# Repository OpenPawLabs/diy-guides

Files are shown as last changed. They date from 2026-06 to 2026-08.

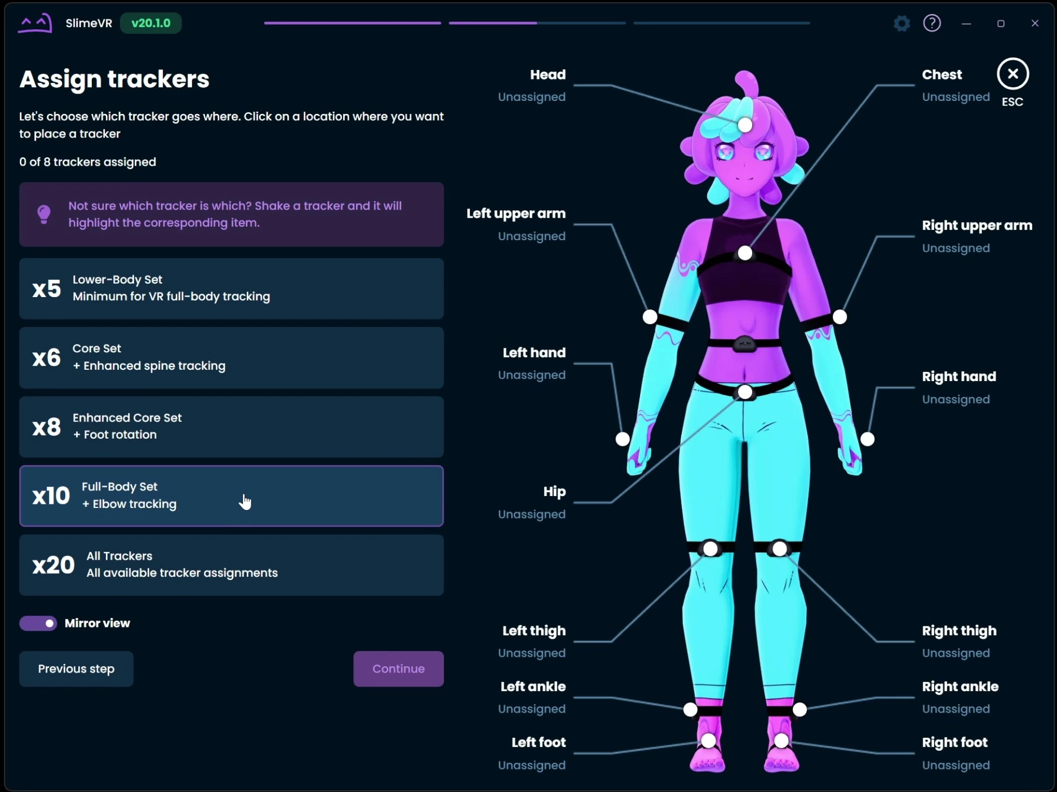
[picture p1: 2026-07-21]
common/0-onetime-tracker-setup/images/slimevr-assign-trackers.webp

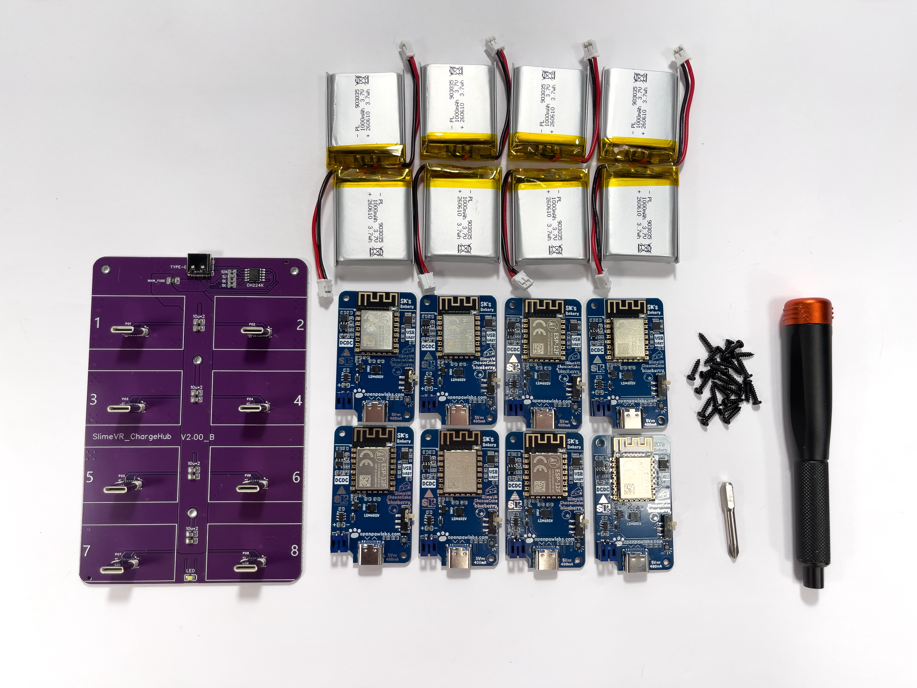
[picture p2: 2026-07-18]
bb-lsm6dsv/0-overview/images/img-4715.webp

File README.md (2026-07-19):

# diy-guides

Contains all of our DIY guides written for OpenPawLabs! Help fix/contribute today!

## Project manifests

Each project folder (for example `bb-lsm6dsv/`) includes a `project.json` that is the source of truth for:

- Project title and description
- **Ordered** list of guides shown on the docs site (cards, prev/next, progress)
- Per-guide card descriptions, plus `optional` / `shared` flags
- Optional route `slug` overrides (used for shared `common/` guides)

Guide display fields (`title`, `difficulty`, `timeEstimate`, `heroImage`, steps) still come from each guide’s `guide.mdx` header — do not duplicate titles in the manifest.

### Conventions

| Field | Meaning |
|---|---|
| `overview` | Project-relative path of the guide whose hero backs the project card |
| `guides[].path` | Project-relative for local guides (`0-overview`), or repo-root-relative for shared guides (`common/…`) |
| `guides[].slug` | Defaults to the final path segment; set only when the URL should differ |
| Array order | Site order |

When you add, remove, or reorder guides, edit `project.json` in the same change. Folders not listed in the manifest stay invisible on the site (useful for WIP drafts). The docs site validates that every listed path has a `guide.mdx`.

## Image scripts

Guides reference local rasters under each guide’s `images/` folder. Two scripts help keep those assets small and tidy.

### Setup

```bash
pip install -r scripts/requirements.txt
```

### Convert referenced images to WebP

Converts every PNG/JPG referenced by a `guide.mdx` to WebP (default quality `92`, full resolution, alpha preserved), rewrites the MDX paths, and deletes the converted originals.

```bash
# Preview without writing
python scripts/convert-images-to-webp.py --dry-run

# Convert (lossy WebP, quality 92)
python scripts/convert-images-to-webp.py

# Optional: custom quality or lossless encode
python scripts/convert-images-to-webp.py --quality 95
python scripts/convert-images-to-webp.py --lossless
```

### Clean up unused images

Reports files under any `images/` directory that no `guide.mdx` references. Deletion is opt-in.

```bash
# List unused files and reclaimable size
python scripts/cleanup-unused-images.py

# Only consider raster images in the report
python scripts/cleanup-unused-images.py --rasters-only

# Delete unused rasters (non-rasters need an extra flag)
python scripts/cleanup-unused-images.py --delete
python scripts/cleanup-unused-images.py --delete --include-non-rasters

# --delete aborts if nothing looks referenced, or if ≥50% of images
# look unused (pass --force only after reviewing that report)
python scripts/cleanup-unused-images.py --delete --force
```

Suggested workflow: convert referenced images, review the cleanup report, then delete unused files.

### Responsive size variants (build hosts, not this repo)

Do **not** commit thumbnail derivatives here. The docs site (and other publishers) run
[`diy-guide-images`](https://github.com/OpenPawLabs/diy-guides-ui-react) from
`@openpawlabs/diy-guides-ui` after syncing this tree, writing AVIF width variants
under `images/thumbnails/` (plus `variants.json`). Authors only commit canonical
sources under each guide’s `images/` folder. Delete `images/thumbnails/` locally
to force a regenerate.

To preview locally:

```bash
pnpm --dir ../diy-guides-ui-react exec diy-guide-images ./bb-lsm6dsv/0-overview
```

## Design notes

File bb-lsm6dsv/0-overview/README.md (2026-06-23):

Contains the guide that references what materials/tools the user needs to acquire to complete the guide. Gives a general overview of the project and acts as the starting point for users.

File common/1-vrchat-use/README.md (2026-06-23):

Walks the user through the steps required in VRChat every time they use their trackers. Quick calibrate in SlimeVR, and click Calibrate in VRChat!

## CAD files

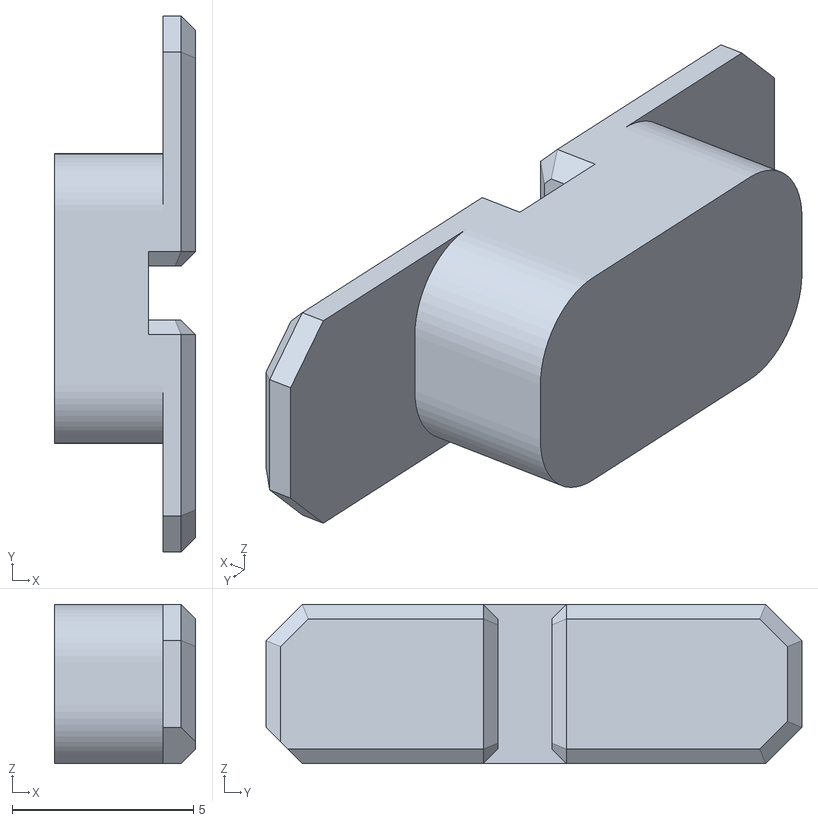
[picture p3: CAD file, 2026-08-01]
bb-lsm6dsv/1-3d-prints/files/003-SW.stl
3.90 x 14.8 x 4.40

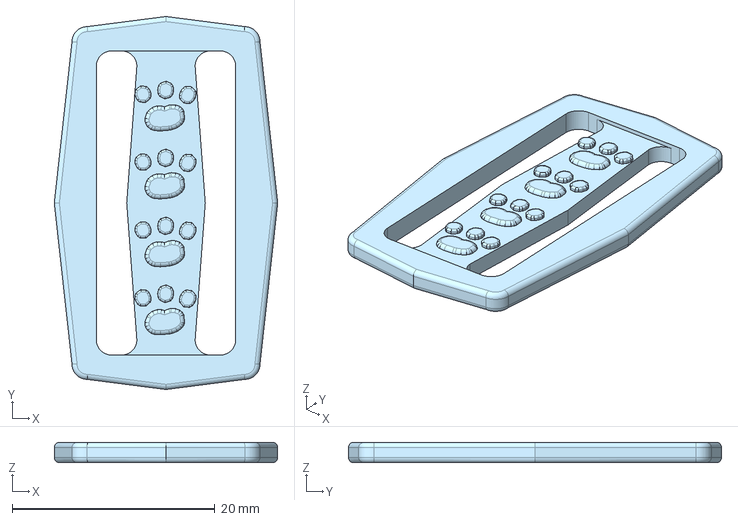
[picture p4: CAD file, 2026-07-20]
bb-lsm6dsv/1-3d-prints/images/glide-slide-v1.step
22.1 x 36.8 x 2.00 mm

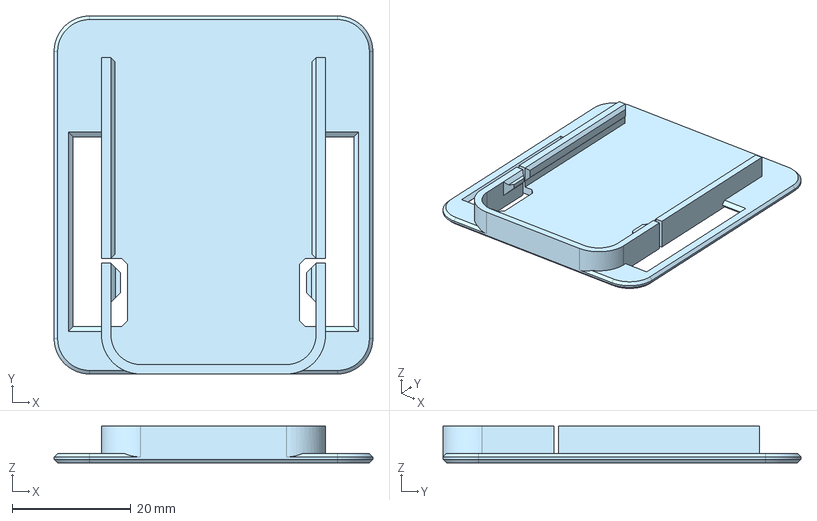
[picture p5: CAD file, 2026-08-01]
bb-lsm6dsv/1-3d-prints/files/openpaw-slide-mount-v5.step
53.8 x 60.4 x 6.20 mm

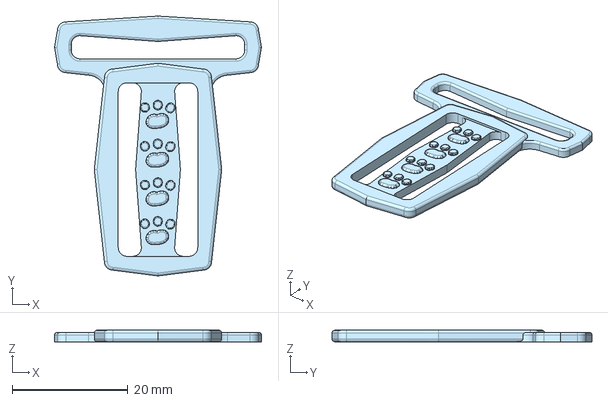
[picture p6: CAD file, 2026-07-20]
bb-lsm6dsv/1-3d-prints/images/3-way-glide-slide-v1.step
35.8 x 45.0 x 2.00 mm

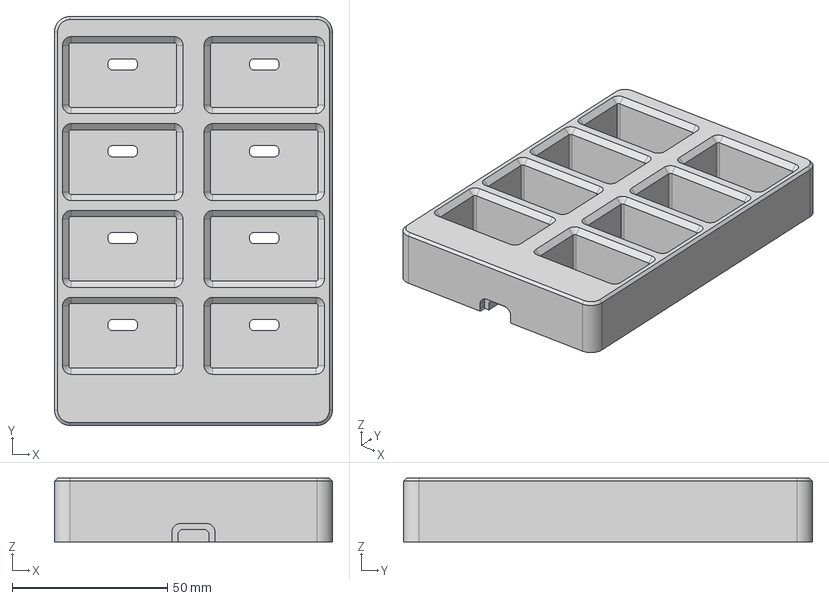
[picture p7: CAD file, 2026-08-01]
bb-lsm6dsv/1-3d-prints/files/charger-dock-dock-top-v3.step
89.6 x 131.8 x 20.6 mm

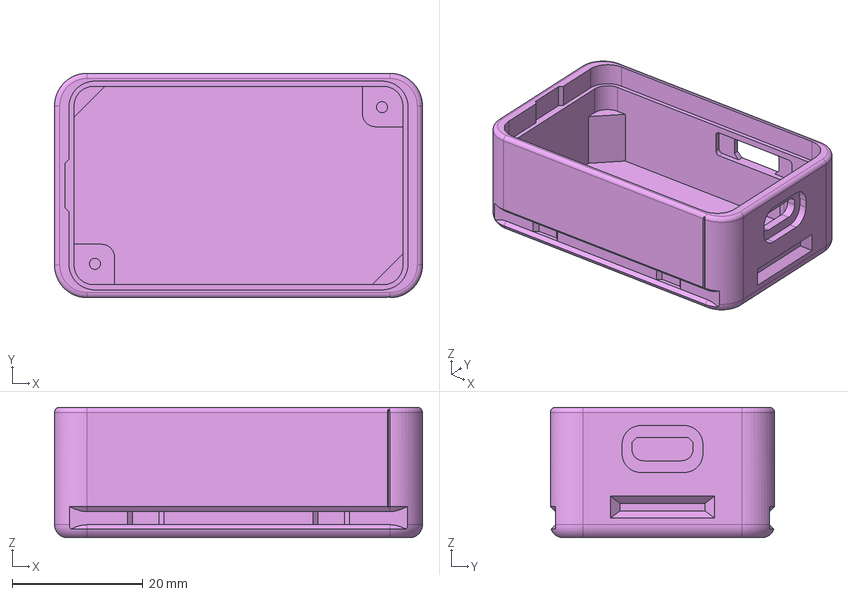
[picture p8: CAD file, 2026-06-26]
bb-lsm6dsv/1-3d-prints/images/openpaw-tracker-case-v7.step
56.4 x 34.4 x 20.0 mm

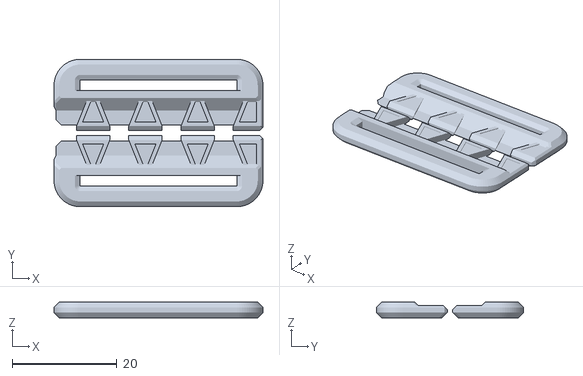
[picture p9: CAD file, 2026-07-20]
bb-lsm6dsv/1-3d-prints/files/latch-30mm-a-moderahn.stl
40.0 x 28.2 x 3.00

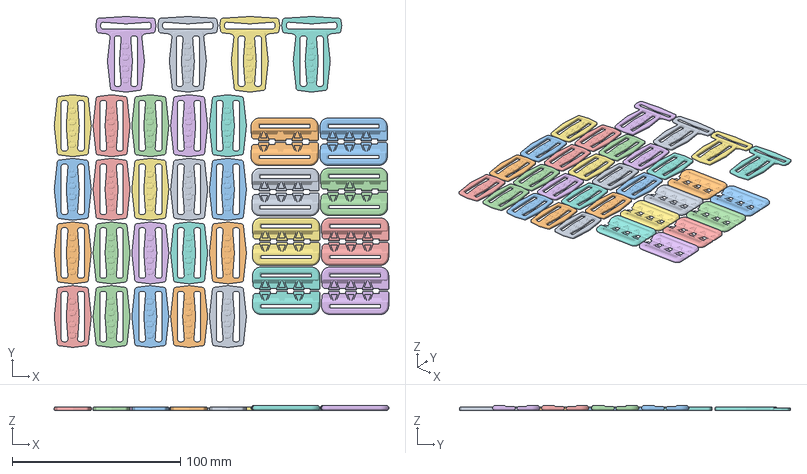
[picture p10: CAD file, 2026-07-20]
bb-lsm6dsv/1-3d-prints/files/diy-strap-hardware.3mf
198.8 x 196.7 x 3.00 mm
Latch_30mm_A.stl x 8
3-way Glide Slide v1.step x 4
Glide Slide v1.step x 20

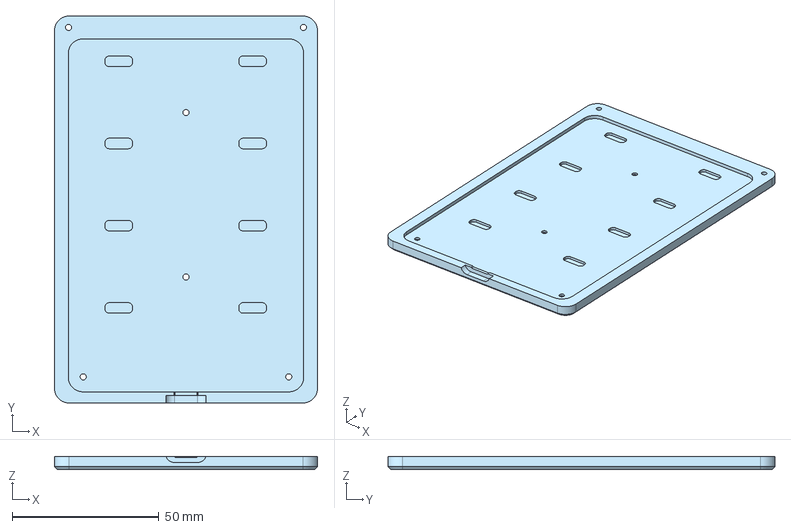
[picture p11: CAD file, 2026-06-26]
bb-lsm6dsv/1-3d-prints/files/charger-dock-dock-bottom-v3-1.step
89.6 x 131.8 x 4.40 mm

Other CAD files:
bb-lsm6dsv/1-3d-prints/files/openpaw-tracker-case-v7.3mf
bb-lsm6dsv/1-3d-prints/files/openpaw-tracker-case-v7.stl

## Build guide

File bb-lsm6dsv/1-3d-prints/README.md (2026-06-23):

Walks the user through 3D printing all the components required for later guides.

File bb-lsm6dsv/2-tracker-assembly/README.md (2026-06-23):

Walks the user through assembling the trackers by attaching batteries, and screwing them together into the cases. Also walks the user through the assembly of the tracker charging dock.

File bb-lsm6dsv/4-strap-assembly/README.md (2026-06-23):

Walks the user through an optional guide for creating their own low cost DIY straps.

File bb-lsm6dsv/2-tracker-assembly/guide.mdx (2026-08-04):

import {
  Callout,
  GuideLayout,
  GuideStep,
  GuideStepList,
  LinkButton,
  MediaFigure,
  ToolList,
} from "@openpawlabs/diy-guides-ui";

<GuideLayout>

  <GuideLayout.Header
    title="Tracker Assembly"
    heroImage="./images/img-4599-2.webp"
    difficulty="easy"
    timeEstimate="45 minutes"
    meta=""
  />

  <GuideLayout.Intro>
    Follow these steps to assemble each of your trackers. This should take roughly 30 minutes total, even going slow.
  </GuideLayout.Intro>

  <GuideLayout.Sidebar>
    <ToolList title="Tools">
      <ToolList.Item name="Philips Screwdriver (#1)" quantity={1} href="https://www.amazon.com/iFixit-IF145-299-4-Driver-Bit-64pc/dp/B0189YWOIO" thumbnail="./images/img-4713.webp" />
    </ToolList>
  </GuideLayout.Sidebar>

  <GuideLayout.Content>
    <GuideStepList>
      <GuideStep title="Read the guide first!">
        <GuideStep.Media />
        <GuideStep.Bullets>
          <GuideStep.Bullet color="RED">
            **Before assembling your first tracker read all of the steps in this guide**!
          </GuideStep.Bullet>
          <GuideStep.Bullet color="GREEN">
            I know you likely want to ignore this and start building your first one, but I can assure you that reading through each step in the guide first will make it much easier for you to build your trackers without any confusion.
          </GuideStep.Bullet>
          <GuideStep.Bullet color="LIGHT_BLUE">
            The instructions in later steps will likely answer questions that you might have when doing the earlier steps.
          </GuideStep.Bullet>
        </GuideStep.Bullets>
      </GuideStep>
      <GuideStep title="Gather Parts">
        <GuideStep.Media>
          <MediaFigure
            src="./images/img-4599-2-1.webp"
            displayRegion={{ x: 14.14, y: 15.83, width: 71.17 }}
          />
        </GuideStep.Media>
        <GuideStep.Bullets>
          <GuideStep.Bullet color="LIGHT_BLUE">
            Grab all of the parts to assemble one tracker along with your Philips #1 Screwdriver.
          </GuideStep.Bullet>
          <GuideStep.Bullet color="RED">
            **You will need:**
            
            1 x Tracker Board
            
            1 x Battery (903035 w/ PH2.0 connector)
            
            2 x M2 8mm Screws (Self Tapping), included in Kit
            
            1 x Tracker Case
            
            1 x Tracker Label Lid
            
            1 x Tracker Power Switch
          </GuideStep.Bullet>
          <GuideStep.Bullet color="GREEN">
            The 3D printing kit comes with 10 labels, but you will only need 8 of them. We suggest building the following trackers based on how many trackers you bought!
            <br />
            
            **REQUIRED**
            
            - 2 x Ankle Trackers
            
            - 2 x Thigh Trackers
            
            - 1 x Chest Tracker
            <br />
            
            **6 Tracker**
            
            - 1 x Hip Tracker
            <br />
            
            **8 Tracker**
            
            - 2 x Upper Arm Tracker (Recommended)
            
            **OR**
            
            - 2 x Foot Tracker
          </GuideStep.Bullet>
          <GuideStep.Bullet variant="note">
            Need a high quality screwdriver? [iFixit has a great kit](https://www.amazon.com/iFixit-IF145-299-4-Driver-Bit-64pc/dp/B0189YWOIO) that will serve you for all of your future building/repair needs!
          </GuideStep.Bullet>
        </GuideStep.Bullets>
      </GuideStep>
      <GuideStep title="Prepare Battery">
        <GuideStep.Media>
          <MediaFigure
            src="./images/img-4600.webp"
            annotations={[
              { type: "point", x: 63.18, y: 20.63, label: "1", color: "RED" },
            ]}
          />
          <MediaFigure
            src="./images/img-4601.webp"
            annotations={[
              { type: "point", x: 40.3, y: 15.21, label: "2", color: "GREEN" },
            ]}
          />
          <MediaFigure
            src="./images/img-4602.webp"
            annotations={[
              { type: "point", x: 73.87, y: 13.92, label: "3", color: "LIGHT_BLUE" },
            ]}
          />
        </GuideStep.Media>
        <GuideStep.Bullets>
          <GuideStep.Bullet variant="note">
            Grab your battery and prepare it by pre-bending the wire into the right shape for later. These bends will puts the connector exactly where it needs to be to connect to the tracker board and will make it easier to do Step 6.
          </GuideStep.Bullet>
          <GuideStep.Bullet color="RED">
            Start by placing the battery like you see in Image 1 with the wire coming out of the Right side of the battery. Bend the wire so that it goes towards the Left to match the first image
          </GuideStep.Bullet>
          <GuideStep.Bullet color="GREEN">
            Bend the wire to match Image 2 by adding a bend back towards the left when the wire is in the center of the battery.
          </GuideStep.Bullet>
          <GuideStep.Bullet color="LIGHT_BLUE">
            Bend the wire to match Image 3 by adding a bend so that the connector points at the Top Left corner of the battery.
          </GuideStep.Bullet>
        </GuideStep.Bullets>
      </GuideStep>
      <GuideStep title="Place Battery &amp; Power Switch in Case">
        <GuideStep.Media>
          <MediaFigure
            src="./images/img-4609.webp"
            annotations={[
              { type: "point", x: 68.98, y: 19.94, label: "2", color: "GREEN" },
              { type: "point", x: 56.48, y: 72.2, label: "1", color: "LIGHT_BLUE" },
              { type: "rectangle", x1: 59.7, y1: 55.52, x2: 79.35, y2: 78.47, color: "LIGHT_BLUE" },
              { type: "rectangle", x1: 58.54, y1: 23.21, x2: 79.35, y2: 52.17, color: "GREEN" },
            ]}
          />
          <MediaFigure src="./images/img-4607.webp" />
        </GuideStep.Media>
        <GuideStep.Bullets>
          <GuideStep.Bullet color="LIGHT_BLUE">
            Place the battery into the tracker case so that the wire is on the side with the opening for the USB-C port.
          </GuideStep.Bullet>
          <GuideStep.Bullet color="GREEN">
            Insert the Power Switch into the case.
          </GuideStep.Bullet>
        </GuideStep.Bullets>
      </GuideStep>
      <GuideStep title="Connect Battery">
        <GuideStep.Media>
          <MediaFigure
            src="./images/img-4614.webp"
            displayRegion={{ x: 51.4, y: 36.54, width: 40.87 }}
            annotations={[
              { type: "rectangle", x1: 9.44, y1: 25.87, x2: 53.51, y2: 68.42, color: "YELLOW" },
            ]}
          />
          <MediaFigure
            src="./images/tracker-pcb-back-full.webp"
            displayRegion={{ x: 0, y: 0, width: 100 }}
            annotations={[
              { type: "circle", x: 67.53, y: 80.71, radius: 7.7, color: "GREEN" },
            ]}
          />
          <MediaFigure
            src="./images/battery-1000mah-side-bend-transparent-cropped-img-4592-2.webp"
            displayRegion={{ x: 0, y: 0, width: 100 }}
          />
        </GuideStep.Media>
        <GuideStep.Bullets>
          <GuideStep.Bullet color="YELLOW">
            Connect the battery to the tracker board, supporting the back/top of the connector on the board while you push the battery connector into the slot.
          </GuideStep.Bullet>
          <GuideStep.Bullet variant="note">
            If you **did not** buy batteries from **OpenPaw Labs** and your batteries **do not** have a connector you will need to solder them to the battery pads on the back of the board. Red goes to (**+**), and Black goes to (**-**)
          </GuideStep.Bullet>
          <GuideStep.Bullet variant="caution">
            If you bought batteries with a connector from somewhere **other than OpenPaw Labs** you need make sure that the **connector is wired correctly**! 
            
            Third party batteries sometimes come with the **wires reversed** and will **damage your tracker** if not fixed.
            <br />
            The Red Wire (**+**) needs to be on the **LEFT side** of the connector. 
            
            The Black Wire (**-**) needs to be on the **RIGHT side** of the connector.
          </GuideStep.Bullet>
        </GuideStep.Bullets>
      </GuideStep>
      <GuideStep title="Insert Tracker at Angle">
        <GuideStep.Media>
          <MediaFigure
            src="./images/img-4615.webp"
            displayRegion={{ x: 35.42, y: 25.23, width: 54.84 }}
            annotations={[
              { type: "rectangle", x1: 46.9, y1: 26.4, x2: 71.36, y2: 48.12, color: "GREEN" },
            ]}
          />
          <MediaFigure
            src="./images/img-4616-2.webp"
            displayRegion={{ x: 27.08, y: 12.43, width: 72.92 }}
            annotations={[
              { type: "rectangle", x1: 57.41, y1: 33.61, x2: 75.52, y2: 63.32, color: "GREEN" },
            ]}
          />
        </GuideStep.Media>
        <GuideStep.Bullets>
          <GuideStep.Bullet variant="caution">
            Make sure to insert the board at an angle like shown. Take care to not catch the switch on the lip above the switch opening. 
            <br />
            **Inserting it at this angle minimizes the risk that you might accidentally break off the power switch later on Step 8 when you push the tracker board down into place!**
          </GuideStep.Bullet>
          <GuideStep.Bullet color="GREEN">
            Insert the tracker board at an angle, **align the power switch on the tracker with the slot on the 3D printed power switch.**
          </GuideStep.Bullet>
          <GuideStep.Bullet color="LIGHT_BLUE">
            This leaves the battery wire accessible for the next step.
          </GuideStep.Bullet>
        </GuideStep.Bullets>
      </GuideStep>
      <GuideStep title="Fold Battery Wire In">
        <GuideStep.Media>
          <MediaFigure
            src="./images/img-4617.webp"
            displayRegion={{ x: 51.79, y: 32.41, width: 33.95 }}
          />
          <MediaFigure
            src="./images/img-4618.webp"
            displayRegion={{ x: 50.02, y: 39.62, width: 30.93 }}
          />
        </GuideStep.Media>
        <GuideStep.Bullets>
          <GuideStep.Bullet color="GREEN">
            While you hold the tracker at an angle, use your finger to bend the battery wire directly downwards behind the connector.
          </GuideStep.Bullet>
          <GuideStep.Bullet color="LIGHT_BLUE">
            Fold the wire into the gap at the end of the case. The bends you did on Step 2 should make the wire already aligned properly.
          </GuideStep.Bullet>
        </GuideStep.Bullets>
      </GuideStep>
      <GuideStep title="Push Down Tracker Board">
        <GuideStep.Media>
          <MediaFigure
            src="./images/img-4619.webp"
            displayRegion={{ x: 8.04, y: 3.84, width: 81.94 }}
          />
          <MediaFigure
            src="./images/img-4622.webp"
            displayRegion={{ x: 29.56, y: 30.59, width: 47.3 }}
          />
        </GuideStep.Media>
        <GuideStep.Bullets>
          <GuideStep.Bullet variant="caution">
            **ALWAYS double check** that the switch on the board is properly aligned with the 3D printed switch and that it is not caught on the wall lip! **The switch WILL break off if it is misaligned and force is applied!**
            <br />
            **NEVER force the board down into place!**
          </GuideStep.Bullet>
          <GuideStep.Bullet color="LIGHT_BLUE">
            Keep the board at an angle so that you can see the battery wire and power switch, then **gently** push the board down until it is resting all the way in the case.
          </GuideStep.Bullet>
          <GuideStep.Bullet color="GREEN">
            Adjust the battery wire as needed to keep it out of the way.
          </GuideStep.Bullet>
        </GuideStep.Bullets>
      </GuideStep>
      <GuideStep title="Screw in Tracker Board">
        <GuideStep.Media>
          <MediaFigure
            src="./images/img-4624-2.webp"
            displayRegion={{ x: 25.62, y: 20.54, width: 54.99 }}
            annotations={[
              { type: "rectangle", x1: 62.89, y1: 18.12, x2: 85.24, y2: 52.61, color: "GREEN" },
              { type: "circle", x: 21.12, y: 69.95, radius: 4.82, color: "GREEN" },
            ]}
          />
          <MediaFigure
            src="./images/img-4626.webp"
            displayRegion={{ x: 25.94, y: 35.25, width: 47.1 }}
            annotations={[
              { type: "circle", x: 80.05, y: 27.28, radius: 5.12, color: "GREEN" },
              { type: "circle", x: 19.29, y: 70.92, radius: 5.04, color: "GREEN" },
            ]}
          />
        </GuideStep.Media>
        <GuideStep.Bullets>
          <GuideStep.Bullet color="GREEN">
            Use a Philips Screwdriver (#1) to screw the tracker board down with 2 x **M2 8mm self tapping screws** that came with your tracker kit.
          </GuideStep.Bullet>
          <GuideStep.Bullet color="LIGHT_BLUE">
            Continue to tighten the screws until the board is securely connected down and you feel them come to a stop.
          </GuideStep.Bullet>
          <GuideStep.Bullet variant="note">
            The screws take a little bit of force to get screwed in the first time. The included self-tapping screws will "cut" a thread into the plastic when they are first screwed in.
          </GuideStep.Bullet>
        </GuideStep.Bullets>
      </GuideStep>
      <GuideStep title="Attach Case Lid">
        <GuideStep.Media>
          <MediaFigure
            src="./images/img-4634.webp"
            displayRegion={{ x: 20.81, y: 13.66, width: 79.19 }}
            annotations={[
              { type: "rectangle", x1: 53.25, y1: 34.97, x2: 65.67, y2: 62.35, color: "GREEN" },
              { type: "rectangle", x1: 39.89, y1: 0.78, x2: 67.71, y2: 10.62, color: "YELLOW" },
              { type: "rectangle", x1: 40.84, y1: 82.61, x2: 69.39, y2: 94.89, color: "YELLOW" },
            ]}
          />
          <MediaFigure src="./images/img-4631.webp" />
          <MediaFigure src="./images/img-4632.webp" />
        </GuideStep.Media>
        <GuideStep.Bullets>
          <GuideStep.Bullet color="GREEN">
            Grab the tracker label/lid and align it with the Battery Connector.
          </GuideStep.Bullet>
          <GuideStep.Bullet color="YELLOW">
            Align the notch at the top of the tracker case with the notch on the tracker label/lid.
          </GuideStep.Bullet>
          <GuideStep.Bullet color="LIGHT_BLUE">
            Push the tracker lid directly down into place until it comes to a stop. It should fit snugly in the tracker case.
          </GuideStep.Bullet>
          <GuideStep.Bullet variant="note">
            It can take some force to get the label to fit snugly down into place. 
            
            If you are having issues, put the lid on partially then place the tracker upside down on a table with the label facing downwards, then push the tracker down into the table to force the label into place.
          </GuideStep.Bullet>
        </GuideStep.Bullets>
      </GuideStep>
      <GuideStep title="Repeat for all trackers">
        <GuideStep.Media>
          <MediaFigure src="./images/img-4734.webp" />
        </GuideStep.Media>
        <GuideStep.Bullets>
          <GuideStep.Bullet color="LIGHT_BLUE">
            Repeat until all of your trackers have been assembled!
          </GuideStep.Bullet>
        </GuideStep.Bullets>
      </GuideStep>
    </GuideStepList>
  </GuideLayout.Content>

</GuideLayout>

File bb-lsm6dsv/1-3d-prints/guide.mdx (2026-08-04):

import {
  Callout,
  GuideLayout,
  GuideStep,
  GuideStepList,
  MediaFigure,
  ToolList,
} from "@openpawlabs/diy-guides-ui";

<GuideLayout>

  <GuideLayout.Header
    title="3D Print Parts"
    heroImage="./images/img-4581.webp"
    heroImageAlt="A full set of 3D printed parts including everything you need to build your trackers!"
    difficulty="moderate"
    timeEstimate="9 hours (Printing)"
    meta=""
  />

  <GuideLayout.Intro>
    Get everything required for the rest of the guides 3D Printed! This step takes the longest, but will make you breeze through the rest of the tasks.
  </GuideLayout.Intro>

  <GuideLayout.Sidebar>
    <ToolList title="Tools">
      <ToolList.Item name="3D Printer" quantity={1} thumbnail="./images/3d-printer.webp" />
    </ToolList>
    <ToolList title="Materials">
      <ToolList.Item name="PLA Filament (240g)" quantity={1} thumbnail="./images/img-4718.webp" />
      <ToolList.Item name="PETG Filament (55g)" quantity={1} thumbnail="./images/img-4719.webp" />
    </ToolList>
  </GuideLayout.Sidebar>

  <GuideLayout.Content>
    <GuideStepList>
      <GuideStep title="Download 3D Print File">
        <GuideStep.Media>
          <MediaFigure
            src="./images/3mf-print-overview-1.webp"
            displayRegion={{ x: 4.1, y: 0, width: 91.81 }}
          />
          <MediaFigure
            src="./images/img-4722.webp"
            displayRegion={{ x: 4.1, y: 0, width: 91.81 }}
          />
        </GuideStep.Media>
        <GuideStep.Bullets>
          <GuideStep.Bullet color="LIGHT_BLUE">
            Download this .3mf file that contains all of the 3D Prints you will need to build the trackers.
          </GuideStep.Bullet>
          <GuideStep.Bullet variant="button">
            <LinkButton>
              <LinkButton.Item href="https://github.com/OpenPawLabs/openpaw-tracker/raw/refs/heads/main/bb-lsm6dsv/3D%20Print%20Files/OpenPaw%20Trackers.3mf" download>Download .3mf</LinkButton.Item>
            </LinkButton>
          </GuideStep.Bullet>
          <GuideStep.Bullet color="GREEN">
            You will need **~233g** of PLA Filament, and **~53g** of PETG Filament. 
             <br/>
            You can print everything in PLA without issue, but we do recommend PETG for the Tracker Strap Mounts for an extra secure fit.
          </GuideStep.Bullet>
          <GuideStep.Bullet color="ORANGE">
            We suggest you print each part with different colors like we have shown here, but you can print all pieces in the same color.
             <br/>
            If printing with multiple colors you will need the following amounts of filament for each part/plate:
             <br/>
            **Tracker Cases:** 80g
            
            **Tracker Switches:** 1.5g
            
            **Tracker Case Tops:** 42g (Base), 7g (Text)
            
            **Charging Dock:** 102g
            
            **Tracker Mounts:** 53g (**PETG Recommended**, PLA Okay)
          </GuideStep.Bullet>
        </GuideStep.Bullets>
      </GuideStep>
      <GuideStep title="Tracker Cases (2.5 hours)">
        <GuideStep.Media>
          <MediaFigure
            src="./images/tracker-cases-print.webp"
            displayRegion={{ x: 11.43, y: 8.05, width: 71.5 }}
          />
          <MediaFigure
            src="./images/tracker-cases.webp"
            displayRegion={{ x: 5.13, y: 0, width: 92.55 }}
          />
          <MediaFigure
            src="./images/openpaw-tracker-case-v7.step"
            type="model"
          />
        </GuideStep.Media>
        <GuideStep.Bullets>
          <GuideStep.Bullet color="LIGHT_BLUE">
            Print out Plate 1 which has a full set of cases. This will take ~2.5 hours.
          </GuideStep.Bullet>
          <GuideStep.Bullet color="GREEN">
            You will need to print out 1 tracker case for each tracker.
          </GuideStep.Bullet>
          <GuideStep.Bullet variant="note">
            **79g of PLA filament**
          </GuideStep.Bullet>
          <GuideStep.Bullet variant="button">
            <LinkButton>
              <LinkButton.Item href="./files/openpaw-tracker-case-v7.step" download>Download .step for Tracker Case</LinkButton.Item>
            </LinkButton>
          </GuideStep.Bullet>
        </GuideStep.Bullets>
      </GuideStep>
      <GuideStep title="Power Switches (12 min)">
        <GuideStep.Media>
          <MediaFigure
            src="./images/img-4574.webp"
            displayRegion={{ x: 22.58, y: 20.43, width: 59.73 }}
          />
        </GuideStep.Media>
        <GuideStep.Bullets>
          <GuideStep.Bullet color="LIGHT_BLUE">
            Print out Plate 2 which has a set of power switches. This will take **~12 min**.
          </GuideStep.Bullet>
          <GuideStep.Bullet variant="note">
            **1.5g of PLA filament**
          </GuideStep.Bullet>
          <GuideStep.Bullet variant="button">
            <LinkButton>
              <LinkButton.Item href="./files/003-SW.stl" download>Download .stl for Power Switch</LinkButton.Item>
            </LinkButton>
          </GuideStep.Bullet>
        </GuideStep.Bullets>
      </GuideStep>
      <GuideStep title="Tracker Lids/Labels (2 hours)">
        <GuideStep.Media>
          <MediaFigure src="./images/img-4568.webp" />
        </GuideStep.Media>
        <GuideStep.Bullets>
          <GuideStep.Bullet color="LIGHT_BLUE">
            Print out Plate 3 which has a set of 10 labels for you to choose from. This will take 2 hours to print.
          </GuideStep.Bullet>
          <GuideStep.Bullet color="YELLOW">
            This Multi-Color print only has **a single color swap**, making it efficient and simple to print.
            <br />
            You can print this with an AMS or even use a single color printer. Single color printers will pause halfway through the print for you to switch the filament from the base color over to the label color, then will resume the print!
          </GuideStep.Bullet>
          <GuideStep.Bullet variant="note">
            **Base Color PLA Filament:** 42g
            
            **Label Color PLA Filament:** 7g
          </GuideStep.Bullet>
          <GuideStep.Bullet variant="button">
            <LinkButton>
              <LinkButton.Item href="https://github.com/OpenPawLabs/openpaw-tracker/tree/main/bb-lsm6dsv/3D%20Print%20Files/Tracker" external>Download Case Tops/Labels</LinkButton.Item>
            </LinkButton>
          </GuideStep.Bullet>
        </GuideStep.Bullets>
      </GuideStep>
      <GuideStep title="Charging Dock Case (2.5 hours)">
        <GuideStep.Media>
          <MediaFigure src="./images/img-4562.webp" />
        </GuideStep.Media>
        <GuideStep.Bullets>
          <GuideStep.Bullet color="LIGHT_BLUE">
            Print out Plate 4 which has the parts for the Charging Dock. This will take roughly 2.5 hours.
          </GuideStep.Bullet>
          <GuideStep.Bullet variant="note">
            **102g of PLA Filament**
          </GuideStep.Bullet>
          <GuideStep.Bullet variant="button">
            <LinkButton>
              <LinkButton.Item href="./files/charger-dock-dock-top-v3.step" download>Download .step for Dock Top</LinkButton.Item>
              <LinkButton.Item href="./files/charger-dock-dock-bottom-v3-1.step" download>Download .step for Dock Bottom</LinkButton.Item>
            </LinkButton>
          </GuideStep.Bullet>
        </GuideStep.Bullets>
      </GuideStep>
      <GuideStep title="Tracker Mounts for Straps (1.5 hours)">
        <GuideStep.Media>
          <MediaFigure src="./images/img-4579.webp" />
        </GuideStep.Media>
        <GuideStep.Bullets>
          <GuideStep.Bullet color="LIGHT_BLUE">
            Print out Plate 5 which has a set of Slide Mounts for you to attach to your Straps. This will take 1.5 hours.
          </GuideStep.Bullet>
          <GuideStep.Bullet variant="note">
            **53g of PETG Filament**
          </GuideStep.Bullet>
          <GuideStep.Bullet color="RED">
            **We highly recommend you print these using PETG filament.** You **can** alternatively print these with PLA if you **do not** have access to PETG but there is a chance of the mounts weakening after a few hundred sessions of repeated use.
          </GuideStep.Bullet>
          <GuideStep.Bullet variant="button">
            <LinkButton>
              <LinkButton.Item href="./files/openpaw-slide-mount-v5.step" download>Download .step for Slide Mount</LinkButton.Item>
            </LinkButton>
          </GuideStep.Bullet>
        </GuideStep.Bullets>
      </GuideStep>
      <GuideStep title="(Optional) DIY Strap Hardware">
        <GuideStep.Media>
          <MediaFigure src="./images/img-4756.webp" />
          <MediaFigure
            src="./images/glide-slide-v1.step"
            type="model"
          />
          <MediaFigure
            src="./images/3-way-glide-slide-v1.step"
            type="model"
          />
        </GuideStep.Media>
        <GuideStep.Bullets>
          <GuideStep.Bullet variant="note">
            This step is **Optional** and you **only** need these parts if you are making your own DIY straps from scratch!
          </GuideStep.Bullet>
          <GuideStep.Bullet color="LIGHT_BLUE">
            Download the .3mf file below and print out a set of DIY Strap Hardware. It includes all the hardware needed for a full set of 8 straps (including Chest Harness).
          </GuideStep.Bullet>
          <GuideStep.Bullet variant="note">
            This takes ~2 hours to print.
            **53g of PLA Filament**
          </GuideStep.Bullet>
          <GuideStep.Bullet variant="button">
            <LinkButton>
              <LinkButton.Item href="./files/diy-strap-hardware.3mf" download>Download .3mf for DIY Straps</LinkButton.Item>
              <LinkButton.Item href="./files/glide-slide-v1.step" download>Download .step for Strap Slide</LinkButton.Item>
              <LinkButton.Item href="./files/3-way-glide-slide-v1.step" download>Download .step for 3-way Strap Slide</LinkButton.Item>
              <LinkButton.Item href="./files/latch-30mm-a-moderahn.stl" download>Download .stl for Strap Latch (MoDErahN)</LinkButton.Item>
            </LinkButton>
          </GuideStep.Bullet>
          <GuideStep.Bullet color="MAGENTA">
            [Full credit to the Latches/Clasps for the straps go to MoDErahN on Thingiverse](https://www.thingiverse.com/thing:6929026)
          </GuideStep.Bullet>
        </GuideStep.Bullets>
      </GuideStep>
      <GuideStep title="3D Printing Done!">
        <GuideStep.Media>
          <MediaFigure src="./images/img-4581-1.webp" />
        </GuideStep.Media>
        <GuideStep.Bullets>
          <GuideStep.Bullet>
            You are now done printing out all the parts you will need for the rest of the guide! This is the slowest guide, but you are now done!
          </GuideStep.Bullet>
        </GuideStep.Bullets>
      </GuideStep>
    </GuideStepList>
  </GuideLayout.Content>

</GuideLayout>

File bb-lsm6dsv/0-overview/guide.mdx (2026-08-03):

import {
  Callout,
  GuideLayout,
  GuideStep,
  GuideStepList,
  MediaFigure,
  ToolList,
} from "@openpawlabs/diy-guides-ui";

<GuideLayout>

  <GuideLayout.Header
    title="Project Overview"
    heroImage="./images/dock-w-pcb-angled-transparent-img-4545.webp"
    difficulty="easy"
    timeEstimate="15 minutes"
    meta=""
  />

  <GuideLayout.Intro>
    Building your own trackers is very simple and has a few basic steps that you will need to follow. 
    
    By the end of this guide you should have all the materials and tools all ready to follow the rest of the guides!
  </GuideLayout.Intro>

  <GuideLayout.Sidebar>
    <ToolList title="Tools">
      <ToolList.Item name="3D Printer" quantity={1} thumbnail="./images/3d-printer.webp" />
      <ToolList.Item name="Philips Screwdriver (#1)" quantity={1} href="https://www.amazon.com/iFixit-IF145-299-4-Driver-Bit-64pc/dp/B0189YWOIO" thumbnail="./images/img-4713-1.webp" />
    </ToolList>
    <ToolList title="Materials">
      <ToolList.Item name="Tracker Boards" quantity={8} href="https://openpawlabs.com/products/diy-slimevr-tracker#kit" price="$25/ea" thumbnail="./images/img-4400-edit.webp" />
      <ToolList.Item name="Batteries (903035 w/ JST PH2.0 connector)" quantity={8} href="https://openpawlabs.com/products/diy-slimevr-tracker#kit" price="$16" thumbnail="./images/battery-1000mah-side-bend-transparent-cropped-img-4592-1.webp" />
      <ToolList.Item name="Charging Dock Board" quantity={1} href="https://openpawlabs.com/products/diy-slimevr-tracker#kit" price="$25" thumbnail="./images/dock-pcb-transparent-img-4443-1.webp" />
      <ToolList.Item name="PLA Filament (~240g)" quantity={1} price="$10" thumbnail="./images/img-4718-1.webp" />
      <ToolList.Item name="PETG Filament (~55g)" quantity={1} price="$5" thumbnail="./images/img-4719-1.webp" />
    </ToolList>
  </GuideLayout.Sidebar>

  <GuideLayout.Content>
    <GuideStepList>
      <GuideStep title="Gather Tools">
        <GuideStep.Media>
          <MediaFigure
            src="./images/img-4713.webp"
            displayRegion={{ x: 14.46, y: 12.73, width: 68.48 }}
            annotations={[
              { type: "rectangle", x1: 27.62, y1: 61.96, x2: 57.78, y2: 77.55, color: "GREEN", title: "Philips PH1" },
            ]}
          />
          <MediaFigure
            src="./images/img-4710.webp"
            displayRegion={{ x: 7.42, y: 2.84, width: 82.56 }}
          />
          <MediaFigure
            src="./images/makerspace-map-preview.webp"
            annotations={[
              { type: "point", x: 78.86, y: 59.99, label: "Makerspace Map", color: "RED" },
            ]}
          />
        </GuideStep.Media>
        <GuideStep.Bullets>
          <GuideStep.Bullet variant="note">
            Building your trackers requires very few tools, we tried to design them to need as few tools as possible to make it extra simple!
          </GuideStep.Bullet>
          <GuideStep.Bullet color="GREEN">
            Grab a Philips Screwdriver, you will want this to be a **#1 tip**. You can also use a smaller Philips #0 screwdriver, but the screws included in the kit are Philips #1. [Don't have one? This small kit from iFixit might be worth picking up.](https://www.amazon.com/iFixit-IF145-299-4-Driver-Bit-64pc/dp/B0189YWOIO)
          </GuideStep.Bullet>
          <GuideStep.Bullet color="LIGHT_BLUE">
            You will need a 3D Printer or access to one. If you don't have a 3D Printer we suggest **asking a friend** for help!
          </GuideStep.Bullet>
          <GuideStep.Bullet color="RED">
            If you can't find a friend to help, we suggest checking if your **school or library** might have a 3D printer you can use! You can also see if your **[local Makerspace](https://makerspace.com/map/)** could let you use one!
          </GuideStep.Bullet>
          <GuideStep.Bullet variant="button">
            <LinkButton>
              <LinkButton.Item href="https://makerspace.com/map/" external>Find a Makerspace here!</LinkButton.Item>
            </LinkButton>
          </GuideStep.Bullet>
          <GuideStep.Bullet variant="note">
            **If you do not have access to a 3D printer at all, you can purchase pre-printed parts on our [Kit Configurator](https://openpawlabs.com/products/diy-slimevr-tracker#kit)**. We highly recommend you ask around to save yourself some money though!
          </GuideStep.Bullet>
        </GuideStep.Bullets>
      </GuideStep>
      <GuideStep title="Get Tracker &amp; Charging Dock Boards">
        <GuideStep.Media>
          <MediaFigure
            src="./images/tracker-board-transparent-1080.webp"
            displayRegion={{ x: 16.72, y: 5.42, width: 65.7 }}
          />
          <MediaFigure src="./images/dock-pcb-transparent-img-4443.webp" />
        </GuideStep.Media>
        <GuideStep.Bullets>
          <GuideStep.Bullet color="LIGHT_BLUE">
            Buy assembled the Tracker Boards, you will need one board for each tracker you plan to build!
          </GuideStep.Bullet>
          <GuideStep.Bullet color="YELLOW">
            Be sure to also buy a Charging Dock board if you plan to build one. Each dock charges up to 8 trackers.
          </GuideStep.Bullet>
          <GuideStep.Bullet color="MAGENTA">
            We include all the screws you will need inside of the kit when you purchase!
          </GuideStep.Bullet>
          <GuideStep.Bullet variant="button">
            <LinkButton>
              <LinkButton.Item href="https://openpawlabs.com/products/diy-slimevr-tracker#kit" external>Buy Trackers, Dock, & Batteries</LinkButton.Item>
            </LinkButton>
          </GuideStep.Bullet>
        </GuideStep.Bullets>
      </GuideStep>
      <GuideStep title="Batteries">
        <GuideStep.Media>
          <MediaFigure
            src="./images/battery-1000mah-side-bend-transparent-img-4592.webp"
            displayRegion={{ x: 33.63, y: 33.18, width: 34.44 }}
          />
        </GuideStep.Media>
        <GuideStep.Bullets>
          <GuideStep.Bullet color="GREEN">
            You will need batteries for each tracker you are building. If you are buying batteries from us they come with a JST (PH2.0) connector for easy connection to the tracker board!
          </GuideStep.Bullet>
          <GuideStep.Bullet variant="note">
            **If you live in a location we are unable to ship batteries to you will need to purchase the batteries separate!** Use one of the links below to buy the **803035** OR **903035** batteries from a 3rd party seller. If you are unable to find batteries with the correct connector (JST PH2.0) then you will **need a soldering iron** to attach the batteries!
          </GuideStep.Bullet>
          <GuideStep.Bullet variant="button">
            <LinkButton>
              <LinkButton.Item href="https://www.aliexpress.us/item/3256807581519732.html">AliExpress 903035 (NO CONNECTOR)</LinkButton.Item>
              <LinkButton.Item href="https://www.aliexpress.com/item/2251832771334312.html?pdp_ext_f=%7B%22sku_id%22%3A%2212000047919040336%22%7D">AliExpress 903035 (NO CONNECTOR)</LinkButton.Item>
              <LinkButton.Item href="https://www.aliexpress.com/item/3256805794073404.html?pdp_ext_f=%7B%22sku_id%22%3A%2212000036646594619%22%7D">AliExpress 803035 (NO CONNECTOR)</LinkButton.Item>
              <LinkButton.Item href="https://www.aliexpress.com/item/3256811701937866.html?pdp_ext_f=%7B%22sku_id%22%3A%2212000056901392718%22%7D">AliExpress 803035 (NO CONNECTOR)</LinkButton.Item>
            </LinkButton>
          </GuideStep.Bullet>
        </GuideStep.Bullets>
      </GuideStep>
      <GuideStep title="Get Straps">
        <GuideStep.Media>
          <MediaFigure
            src="./images/vyrovr-comfort-straps.webp"
            annotations={[
              { type: "point", x: 50.11, y: 47.61, label: "Comfort Straps", color: "GREEN" },
            ]}
          />
          <MediaFigure
            src="./images/body-strap-set-img-4863.webp"
            annotations={[
              { type: "point", x: 48.39, y: 89.97, label: "DIY Straps", color: "LIGHT_BLUE" },
            ]}
          />
        </GuideStep.Media>
        <GuideStep.Bullets>
          <GuideStep.Bullet variant="note">
            You can either [build your own DIY Straps](https://docs.openpawlabs.com/projects/bb-lsm6dsv/diy-straps) or purchase some nicer straps from someone in the community!
          </GuideStep.Bullet>
          <GuideStep.Bullet color="GREEN">
            We recommend that you buy a set of straps from VYR0 VR or another community creator! Any pre-made straps should work just fine!
            
            You can find a few options here:
          </GuideStep.Bullet>
          <GuideStep.Bullet variant="button">
            <LinkButton>
              <LinkButton.Item href="https://vyrovr.com/products/10-elastic-full-body-tracker-straps" external>($28) VYR0 VR Full Body Strap Set</LinkButton.Item>
            </LinkButton>
          </GuideStep.Bullet>
          <GuideStep.Bullet variant="button">
            <LinkButton>
              <LinkButton.Item href="https://vyrovr.com/products/vyro-vr-comfort-strap-bundles?variant=45071132196943" external>($156) VYRO VR Comfort Strap Bundle</LinkButton.Item>
            </LinkButton>
          </GuideStep.Bullet>
          <GuideStep.Bullet variant="button">
            <LinkButton>
              <LinkButton.Item href="https://ko-fi.com/s/7acfefe9a7" external>($17) Pixel Strap Bundle (Kit 7+3)</LinkButton.Item>
            </LinkButton>
          </GuideStep.Bullet>
          <GuideStep.Bullet variant="button">
            <LinkButton>
              <LinkButton.Item href="https://ventifbt.store/products/venti-comfort-straps" external>Venti Comfort Straps</LinkButton.Item>
              <LinkButton.Item href="https://ventifbt.store/products/tracker-straps" external>Venti Velco Straps</LinkButton.Item>
            </LinkButton>
          </GuideStep.Bullet>
          <GuideStep.Bullet color="LIGHT_BLUE">
            If you are on a tight budget and cannot afford straps from the community, you can always [build your own DIY Straps for around $12](https://docs.openpawlabs.com/projects/bb-lsm6dsv/diy-straps), making it very affordable. They work pretty well, and you can always buy nicer straps later.
          </GuideStep.Bullet>
        </GuideStep.Bullets>
      </GuideStep>
      <GuideStep title="Get 3D Printer Filament">
        <GuideStep.Media>
          <MediaFigure src="./images/img-4722.webp" />
          <MediaFigure
            src="./images/img-4718.webp"
            annotations={[
              { type: "rectangle", x1: 19.66, y1: 26.3, x2: 86.92, y2: 71.31, color: "LIGHT_BLUE" },
            ]}
          />
          <MediaFigure
            src="./images/img-4719.webp"
            annotations={[
              { type: "rectangle", x1: 25.28, y1: 26.89, x2: 92.39, y2: 71.99, color: "GREEN" },
            ]}
          />
        </GuideStep.Media>
        <GuideStep.Bullets>
          <GuideStep.Bullet>
            For the later steps of the guide you will need to get some filament for your 3D printer, here is the exact amounts you need!
          </GuideStep.Bullet>
          <GuideStep.Bullet color="LIGHT_BLUE">
            **PLA Filament:** ~240g
          </GuideStep.Bullet>
          <GuideStep.Bullet color="GREEN">
            **PETG Filament:** ~55g
          </GuideStep.Bullet>
          <GuideStep.Bullet variant="note">
            The **PETG Filament** is recommended to print out the Tracker Slide Mounts for the Straps so that they never wear out. If you **do not have access to PETG** you _can_ print out the Strap Slide Mounts with PLA but we do not recommend it since PLA fatigues over time.
          </GuideStep.Bullet>
        </GuideStep.Bullets>
      </GuideStep>
      <GuideStep title="You are ready!">
        <GuideStep.Media>
          <MediaFigure src="./images/img-4715.webp" />
          <MediaFigure src="./images/party-face-emoji-big.webp" />
        </GuideStep.Media>
        <GuideStep.Bullets>
          <GuideStep.Bullet color="GREEN">
            You should now have all the tools and materials you need to follow the rest of the guides! Take some time to celebrate then continue on to the next guide!
          </GuideStep.Bullet>
        </GuideStep.Bullets>
      </GuideStep>
    </GuideStepList>
  </GuideLayout.Content>

</GuideLayout>

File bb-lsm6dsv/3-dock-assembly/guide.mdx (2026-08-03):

import {
  Callout,
  GuideLayout,
  GuideStep,
  GuideStepList,
  LinkButton,
  MediaFigure,
  ToolList,
} from "@openpawlabs/diy-guides-ui";

<GuideLayout>

  <GuideLayout.Header
    title="Dock Assembly"
    heroImage="./images/img-4638.webp"
    difficulty="easy"
    timeEstimate="5 minutes"
    meta=""
  />

  <GuideLayout.Intro>
    Assemble the Charging Dock.
  </GuideLayout.Intro>

  <GuideLayout.Sidebar>
    <ToolList title="Tools">
      <ToolList.Item name="Philips Screwdriver (#1)" quantity={1} thumbnail="./images/img-4713.webp" />
    </ToolList>
  </GuideLayout.Sidebar>

  <GuideLayout.Content>
    <GuideStepList>
      <GuideStep title="Gather Materials">
        <GuideStep.Media>
          <MediaFigure src="./images/img-4636-2.webp" />
        </GuideStep.Media>
        <GuideStep.Bullets>
          <GuideStep.Bullet color="LIGHT_BLUE">
            Grab all of the parts you need to build the Charging Dock
          </GuideStep.Bullet>
          <GuideStep.Bullet color="RED">
            **You will need:**
            
            1 x Charging Dock Board
            
            6 x M2 8mm Screws (Self Tapping), included in Kit
            
            1 x Dock Case Top
            
            1 x Dock Case Bottom
          </GuideStep.Bullet>
        </GuideStep.Bullets>
      </GuideStep>
      <GuideStep title="Put Charging PCB in Case">
        <GuideStep.Media>
          <MediaFigure
            src="./images/img-4637.webp"
            annotations={[
              { type: "circle", x: 54.7, y: 83.54, radius: 8.97, color: "GREEN" },
            ]}
          />
        </GuideStep.Media>
        <GuideStep.Bullets>
          <GuideStep.Bullet color="GREEN">
            Align the USB-C port with the notch on the case and push the charger board into the bottom of the Charging Dock case.
          </GuideStep.Bullet>
        </GuideStep.Bullets>
      </GuideStep>
      <GuideStep title="Put on Case Top">
        <GuideStep.Media>
          <MediaFigure
            src="./images/img-4638-1.webp"
            displayRegion={{ x: 2.66, y: 20.38, width: 71.72 }}
          />
        </GuideStep.Media>
        <GuideStep.Bullets>
          <GuideStep.Bullet color="GREEN">
            Align the USB-C port cutouts and place the top of the Charging Dock case on top of the charger board.
          </GuideStep.Bullet>
        </GuideStep.Bullets>
      </GuideStep>
      <GuideStep title="Screw together">
        <GuideStep.Media>
          <MediaFigure
            src="./images/img-4641.webp"
            annotations={[
              { type: "circle", x: 32.91, y: 9.61, radius: 2.78, color: "RED" },
              { type: "circle", x: 70.64, y: 9.73, radius: 2.83, color: "RED" },
              { type: "circle", x: 51.78, y: 27.6, radius: 2.83, color: "RED" },
              { type: "circle", x: 51.69, y: 62.62, radius: 2.77, color: "RED" },
              { type: "circle", x: 35.01, y: 84.26, radius: 2.73, color: "RED" },
              { type: "circle", x: 68.36, y: 84.38, radius: 2.58, color: "RED" },
            ]}
          />
        </GuideStep.Media>
        <GuideStep.Bullets>
          <GuideStep.Bullet color="GREEN">
            Grab your Philips #1 Screwdriver
          </GuideStep.Bullet>
          <GuideStep.Bullet color="RED">
            Use 6 x M2 8mm screws to connect the Charging Dock case together
          </GuideStep.Bullet>
        </GuideStep.Bullets>
      </GuideStep>
      <GuideStep title="Dock Complete!">
        <GuideStep.Media>
          <MediaFigure src="./images/dock-w-case-transparent-img-4436.webp" />
          <MediaFigure src="./images/trackers-transparent-img-4525.webp" />
        </GuideStep.Media>
        <GuideStep.Bullets>
          <GuideStep.Bullet color="GREEN">
            You are done! Go ahead and place all of your trackers into the Charging Dock.
          </GuideStep.Bullet>
        </GuideStep.Bullets>
      </GuideStep>
    </GuideStepList>
  </GuideLayout.Content>

</GuideLayout>

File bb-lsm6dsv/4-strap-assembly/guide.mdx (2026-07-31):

import {
  Callout,
  GuideLayout,
  GuideStep,
  GuideStepList,
  LinkButton,
  MediaFigure,
  ToolList,
} from "@openpawlabs/diy-guides-ui";

<GuideLayout>

  <GuideLayout.Header
    title="Community Strap Assembly"
    heroImage="./images/img-4657-2.webp"
    difficulty="easy"
    timeEstimate="5 minutes"
    meta=""
  />

  <GuideLayout.Intro>
    Attach all of the tracker slide mounts onto your straps!
  </GuideLayout.Intro>

  <GuideLayout.Content>
    <GuideStepList>
      <GuideStep title="Gather Materials">
        <GuideStep.Media>
          <MediaFigure src="./images/img-4644.webp" />
        </GuideStep.Media>
        <GuideStep.Bullets>
          <GuideStep.Bullet color="GREEN">
            Grab your Straps and the Tracker Slide Mounts.
          </GuideStep.Bullet>
          <GuideStep.Bullet color="LIGHT_BLUE">
            If you do not have Straps you either need to buy 3rd party straps (recommended), or you need [to make your DIY Straps](https://docs.openpawlabs.com/projects/bb-lsm6dsv/diy-straps).
          </GuideStep.Bullet>
          <GuideStep.Bullet color="GREEN">
            We recommend you buy a set of straps from VYR0 VR or another community creator! Almost any pre-made straps should work just fine. The tracker mounts are designed to fit 30mm straps.
            <br />
            Community strap recommendations:
          </GuideStep.Bullet>
          <GuideStep.Bullet variant="button">
            <LinkButton>
              <LinkButton.Item href="https://vyrovr.com/products/10-elastic-full-body-tracker-straps" external>($28) VYR0 VR Full Body Strap Set</LinkButton.Item>
            </LinkButton>
          </GuideStep.Bullet>
          <GuideStep.Bullet variant="button">
            <LinkButton>
              <LinkButton.Item href="https://vyrovr.com/products/vyro-vr-comfort-strap-bundles?variant=45071132196943" external>($156) VYRO VR Comfort Strap Bundle</LinkButton.Item>
            </LinkButton>
          </GuideStep.Bullet>
          <GuideStep.Bullet variant="button">
            <LinkButton>
              <LinkButton.Item href="https://ko-fi.com/s/7acfefe9a7" external>($17) Pixel Strap Bundle (Kit 7+3)</LinkButton.Item>
            </LinkButton>
          </GuideStep.Bullet>
          <GuideStep.Bullet variant="button">
            <LinkButton>
              <LinkButton.Item href="https://ventifbt.store/products/venti-comfort-straps" external>Venti Comfort Straps</LinkButton.Item>
              <LinkButton.Item href="https://ventifbt.store/products/tracker-straps" external>Venti Velco Straps</LinkButton.Item>
            </LinkButton>
          </GuideStep.Bullet>
        </GuideStep.Bullets>
      </GuideStep>
      <GuideStep title="Open Strap">
        <GuideStep.Media>
          <MediaFigure
            src="./images/img-4645.webp"
            displayRegion={{ x: 5.6, y: 1.92, width: 87.64 }}
          />
          <MediaFigure
            src="./images/img-4646.webp"
            displayRegion={{ x: 9.55, y: 3.42, width: 90.45 }}
          />
        </GuideStep.Media>
        <GuideStep.Bullets>
          <GuideStep.Bullet color="GREEN">
            Undo the velcro on the strap and grab one of the tracker mounts.
          </GuideStep.Bullet>
        </GuideStep.Bullets>
      </GuideStep>
      <GuideStep title="Attach Tracker Mount">
        <GuideStep.Media>
          <MediaFigure
            src="./images/img-4647-2.webp"
            displayRegion={{ x: 23.99, y: 17.15, width: 71.26 }}
          />
          <MediaFigure
            src="./images/img-4650.webp"
            displayRegion={{ x: 12.99, y: 5.1, width: 72.38 }}
          />
          <MediaFigure
            src="./images/img-4652.webp"
            displayRegion={{ x: 9.48, y: 3.74, width: 89.58 }}
          />
        </GuideStep.Media>
        <GuideStep.Bullets>
          <GuideStep.Bullet color="GREEN">
            Thread the strap through each hole so that it is running along the back of the tracker mount.
          </GuideStep.Bullet>
          <GuideStep.Bullet color="LIGHT_BLUE">
            Attach the velcro back down to the strap
          </GuideStep.Bullet>
        </GuideStep.Bullets>
      </GuideStep>
      <GuideStep title="Repeat for all Straps">
        <GuideStep.Media>
          <MediaFigure
            src="./images/img-4653.webp"
            displayRegion={{ x: 5.48, y: 0.18, width: 89.33 }}
          />
          <MediaFigure
            src="./images/img-4656-2.webp"
            displayRegion={{ x: 11.42, y: 2.25, width: 88.58 }}
          />
        </GuideStep.Media>
        <GuideStep.Bullets>
          <GuideStep.Bullet color="GREEN">
            Attach the tracker mounts to each strap
          </GuideStep.Bullet>
          <GuideStep.Bullet color="LIGHT_BLUE">
            You are done and ready to move on to setting up SlimeVR/VRChat!
          </GuideStep.Bullet>
        </GuideStep.Bullets>
      </GuideStep>
    </GuideStepList>
  </GuideLayout.Content>

</GuideLayout>

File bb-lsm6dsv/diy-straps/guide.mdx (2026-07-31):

import {
  Callout,
  GuideLayout,
  GuideStep,
  GuideStepList,
  LinkButton,
  MediaFigure,
  ToolList,
} from "@openpawlabs/diy-guides-ui";

<GuideLayout>

  <GuideLayout.Header
    title="DIY Straps (Optional)"
    heroImage="./images/body-strap-set-img-4863.webp"
    difficulty="moderate"
    timeEstimate="60 minutes"
    meta=""
  />

  <GuideLayout.Intro>
    Make your own straps to save some money when building your FBT kit! You can assemble a full set of 8 straps in about an hour, and it will cost ~$15 total, making it extremely affordable. Makes an entire set that includes straps for Ankles, Thighs, Upper Arms, Hip, and Chest.
  </GuideLayout.Intro>

  <GuideLayout.Content>
    <GuideStepList>
      <GuideStep title="Gather Materials">
        <GuideStep.Media>
          <MediaFigure
            src="./images/diy-strap-set-img-4812.webp"
            displayRegion={{ x: 4.59, y: 6.78, width: 88.68 }}
            annotations={[
              { type: "point", x: 21.52, y: 27.1, label: "1", color: "GREEN" },
              { type: "point", x: 21.85, y: 51.46, label: "2", color: "LIGHT_BLUE" },
              { type: "point", x: 11.53, y: 63.61, label: "3", color: "RED" },
              { type: "rectangle", x1: 28.07, y1: 6.96, x2: 100, y2: 91.74, color: "YELLOW" },
              { type: "point", x: 56.55, y: 53.31, label: "4", color: "YELLOW" },
            ]}
          />
          <MediaFigure src="./images/roll-of-material-img-4818.webp" />
        </GuideStep.Media>
        <GuideStep.Bullets>
          <GuideStep.Bullet variant="note">
            You will need to get the following parts/tools:
          </GuideStep.Bullet>
          <GuideStep.Bullet color="GREEN">
            **Elastic Straps w/ Silicon Grips** (width: 30mm / ~1.2in)
          </GuideStep.Bullet>
          <GuideStep.Bullet color="LIGHT_BLUE">
            **Small Lighter**
          </GuideStep.Bullet>
          <GuideStep.Bullet color="RED">
            **Scissors**
          </GuideStep.Bullet>
          <GuideStep.Bullet color="YELLOW">
            **3D Printed Parts for Straps** ([check 3d print guide here](https://docs.openpawlabs.com/projects/bb-lsm6dsv/1-3d-prints#step-7))
          </GuideStep.Bullet>
          <GuideStep.Bullet variant="button">
            <LinkButton>
              <LinkButton.Item href="https://www.amazon.com/dp/B097XC3NZJ" external>($12) 10m Elastic Straps 1.1in (Amazon)</LinkButton.Item>
              <LinkButton.Item href="https://www.amazon.com/dp/B092SM7Z2V" external>($12) 10m Elastic Straps 1.2in (Amazon)</LinkButton.Item>
              <LinkButton.Item href="https://www.amazon.com/dp/B0FBS4CYGP" external>($10) 6m Elastic Straps 1 3/16in (Amazon)</LinkButton.Item>
              <LinkButton.Item href="https://www.amazon.com/dp/B0GRV4KTM5" external>($8x2) 5m Elastic Straps 1.2in (Amazon)</LinkButton.Item>
              <LinkButton.Item href="https://www.amazon.com/dp/B0F8J45BMT" external>($9x2) 5m Elastic Straps 1.2in (Amazon)</LinkButton.Item>
              <LinkButton.Item href="https://www.amazon.com/dp/B09PD3VRHQ" external>($9x2) 6m Elastic Strap 1in (Amazon)</LinkButton.Item>
            </LinkButton>
          </GuideStep.Bullet>
        </GuideStep.Bullets>
      </GuideStep>
      <GuideStep title="Measure &amp; Cut Strap">
        <GuideStep.Media>
          <MediaFigure src="./images/cut-to-length-img-4819.webp" />
          <MediaFigure src="./images/extra-strap-length-img-4814.webp" />
          <MediaFigure src="./images/wrapped-strap-img-4815.webp" />
        </GuideStep.Media>
        <GuideStep.Bullets>
          <GuideStep.Bullet color="GREEN">
            Cut the strap to the proper length by wrapping it around your body part loosely as a rough measurement, then add an additional 3-4in (75-100mm) of length.
          </GuideStep.Bullet>
          <GuideStep.Bullet color="LIGHT_BLUE">
            You will need sections for your:
            
            - **2 x Ankles** (just above your ankle/foot)
            
            - **2 x Thighs** (the middle of your thigh)
            
            - **2 x Upper Arms** (where your bicep is)
            
            - **Hip** (where you wear a belt)
          </GuideStep.Bullet>
          <GuideStep.Bullet variant="note">
            It is better to have too much extra length vs not enough length. You can always trim them shorter later!
          </GuideStep.Bullet>
        </GuideStep.Bullets>
      </GuideStep>
      <GuideStep title="Melt Ends">
        <GuideStep.Media>
          <MediaFigure
            src="./images/melting-strap-fray.mp4"
            type="video"
          />
          <MediaFigure src="./images/strap-cut-to-length-frayed-img-4822.webp" />
        </GuideStep.Media>
        <GuideStep.Bullets>
          <GuideStep.Bullet color="ORANGE">
            To stop the ends fraying, take your lighter and move it over the end of the strap for ~1 second to melt/seal the end of the strap.
          </GuideStep.Bullet>
          <GuideStep.Bullet color="RED">
            See video for an example of how to do this. A quick pass over the end is enough to prevent future fraying.
          </GuideStep.Bullet>
          <GuideStep.Bullet variant="caution">
            **Do not** leave the lighter on the end for more than a couple seconds, as **it could catch fire**!
          </GuideStep.Bullet>
        </GuideStep.Bullets>
      </GuideStep>
      <GuideStep title="Grab Strap Parts">
        <GuideStep.Media>
          <MediaFigure src="./images/strap-and-parts-img-4830.webp" />
          <MediaFigure
            src="./images/clasp-alignment-img-4828.webp"
            annotations={[
              { type: "rectangle", x1: 38.51, y1: 71.31, x2: 65.1, y2: 87.15, color: "LIGHT_BLUE" },
            ]}
          />
          <MediaFigure src="./images/clasps-together-img-4861.webp" />
        </GuideStep.Media>
        <GuideStep.Bullets>
          <GuideStep.Bullet color="GREEN">
            Grab a set of parts to build your strap, you will need:
            
            - **1 x Tracker Slide Mount**
            
            - **2 x Strap Slides**
            
            - **1 pair of Clasps**
          </GuideStep.Bullet>
          <GuideStep.Bullet color="LIGHT_BLUE">
            Double check that the clasps you grab are a paired set and that they are able to connect to each other. When facing upwards **each side's tabs should line up with each other**.
          </GuideStep.Bullet>
        </GuideStep.Bullets>
      </GuideStep>
      <GuideStep title="Attach Slide">
        <GuideStep.Media>
          <MediaFigure src="./images/strap-threading-pt1-img-4834.webp" />
          <MediaFigure src="./images/strap-threading-pt2-img-4839.webp" />
        </GuideStep.Media>
        <GuideStep.Bullets>
          <GuideStep.Bullet color="LIGHT_BLUE">
            Attach the Slide to the strap by feeding the strap upwards through one end of the side, over the paw-print grips, then back down and out the other side.
          </GuideStep.Bullet>
          <GuideStep.Bullet color="YELLOW">
            **Make sure that the silicon side of the strap is facing towards the paw-print grips.** This helps make sure it will not move.
          </GuideStep.Bullet>
        </GuideStep.Bullets>
      </GuideStep>
      <GuideStep title="Attach Clasp">
        <GuideStep.Media>
          <MediaFigure src="./images/strap-clasp-threading-pt1-img-4844.webp" />
          <MediaFigure src="./images/strap-threading-pt3-img-4845.webp" />
          <MediaFigure src="./images/strap-threading-pt4img-4846.webp" />
        </GuideStep.Media>
        <GuideStep.Bullets>
          <GuideStep.Bullet color="LIGHT_BLUE">
            Feed the strap upwards through the side of the Clasp, then feed it back through the Slide, making sure that the silicon is now facing upwards.
          </GuideStep.Bullet>
        </GuideStep.Bullets>
      </GuideStep>
      <GuideStep title="Attach Tracker Slide Mount">
        <GuideStep.Media>
          <MediaFigure src="./images/strap-threading-img-4850.webp" />
          <MediaFigure src="./images/thread-strap-mount-img-4849.webp" />
        </GuideStep.Media>
        <GuideStep.Bullets>
          <GuideStep.Bullet color="GREEN">
            Take your Tracker Slide Mount and thread it onto the strap, feeding the strap behind the slide mount.
          </GuideStep.Bullet>
        </GuideStep.Bullets>
      </GuideStep>
      <GuideStep title="Attach Second Clasp">
        <GuideStep.Media>
          <MediaFigure src="./images/strap-clasp-two-img-4852.webp" />
          <MediaFigure src="./images/sull-strap-img-4854.webp" />
          <MediaFigure src="./images/strap-standing-img-4857.webp" />
        </GuideStep.Media>
        <GuideStep.Bullets>
          <GuideStep.Bullet color="LIGHT_BLUE">
            Repeat steps 5 & 6 to thread on a second Slide, making sure that the other end of the clasp is **facing downwards**.
          </GuideStep.Bullet>
          <GuideStep.Bullet color="GREEN">
            **Verify that you can connect the two ends of the clasps together.**
          </GuideStep.Bullet>
        </GuideStep.Bullets>
      </GuideStep>
      <GuideStep title="Tighten Straps">
        <GuideStep.Media>
          <MediaFigure src="./images/tighten-straps-img-4858.webp" />
        </GuideStep.Media>
        <GuideStep.Bullets>
          <GuideStep.Bullet color="LIGHT_BLUE">
            Put on your strap and tighten down the straps moving the Slides to be adjacent to the Clasp halves.
          </GuideStep.Bullet>
          <GuideStep.Bullet color="ORANGE">
            To **tighten** the strap, move the slide away from the clasp, then **hold** the loose end of the strap and pull while moving the slide towards the clasp.
          </GuideStep.Bullet>
          <GuideStep.Bullet color="YELLOW">
            To **loosen** the strap, move the slide away from the clasp, then move it back towards the clasp **without holding** the loose end of the strap.
          </GuideStep.Bullet>
          <GuideStep.Bullet variant="note">
            If the ends of the straps are getting in the way, you can trim them back, making sure to leave 1-2 inches behind the Slides. Just make sure to repeat step 3 and melt the ends again to prevent fraying.
          </GuideStep.Bullet>
        </GuideStep.Bullets>
      </GuideStep>
      <GuideStep title="Repeat for other Straps">
        <GuideStep.Media>
          <MediaFigure src="./images/body-strap-set-img-4863-1.webp" />
        </GuideStep.Media>
        <GuideStep.Bullets>
          <GuideStep.Bullet color="GREEN">
            Repeat steps 2-9 until you have completed all of the straps **except** for your chest harness. Make sure to make the following straps:
            
            - **2 x Ankles**
            
            - **2 x Thighs**
            
            - **2 x Upper Arms**
            
            - **Hip** (Belt line)
          </GuideStep.Bullet>
        </GuideStep.Bullets>
      </GuideStep>
      <GuideStep title="Measure Chest Straps">
        <GuideStep.Media>
          <MediaFigure src="./images/chest-straps-cut-to-length-img-4866-2.webp" />
        </GuideStep.Media>
        <GuideStep.Bullets>
          <GuideStep.Bullet color="LIGHT_BLUE">
            Measure a chest strap just under your armpits, across the **top** of your chest and across your back.
          </GuideStep.Bullet>
          <GuideStep.Bullet color="YELLOW">
            Estimate/measure shoulder straps by placing the strap material over your shoulder, going from the top of your shoulder blade to the top of your chest (where you measured the strap going around your chest)
          </GuideStep.Bullet>
          <GuideStep.Bullet color="RED">
            Add a 3-4" (75-100mm) extra to these measurements, you can always come back and trim off extra material later if it is too long after testing the fit!
          </GuideStep.Bullet>
        </GuideStep.Bullets>
      </GuideStep>
      <GuideStep title="Chest Harness Parts">
        <GuideStep.Media>
          <MediaFigure src="./images/chest-strap-parts-img-4869-1.webp" />
        </GuideStep.Media>
        <GuideStep.Bullets>
          <GuideStep.Bullet color="LIGHT_BLUE">
            Grab the remaining parts to assemble your chest harness. You will need:
            
            - **1 x Tracker Slide Mount**
            
            - **4 x 3-way Slides**
            
            - **6 x normal Slides**
            
            - **1 pair of Clasps**
          </GuideStep.Bullet>
        </GuideStep.Bullets>
      </GuideStep>
      <GuideStep title="Attach 3-Way Slides">
        <GuideStep.Media>
          <MediaFigure src="./images/chest-strap-3-ways-img-4871.webp" />
          <MediaFigure src="./images/chest-straps-pt1-img-4870.webp" />
          <MediaFigure
            src="./images/chest-strap-parts-img-4869-2.webp"
            displayRegion={{ x: 23.45, y: 46.74, width: 44.03 }}
          />
        </GuideStep.Media>
        <GuideStep.Bullets>
          <GuideStep.Bullet color="LIGHT_BLUE">
            Attach all four 3-way Slides onto the strap that goes around your chest.  Make sure that the silicon on the straps is touching the paw-print grips.
          </GuideStep.Bullet>
          <GuideStep.Bullet color="GREEN">
            Align the 3-way Slides so that they are roughly in the same places as shown in the second image.
          </GuideStep.Bullet>
        </GuideStep.Bullets>
      </GuideStep>
      <GuideStep title="Attach Slide Mount">
        <GuideStep.Media>
          <MediaFigure src="./images/chest-strap-balance-img-4874.webp" />
          <MediaFigure src="./images/strap-balance-closeup-img-4875.webp" />
          <MediaFigure src="./images/chest-strap-3-ways-pt2-img-4873.webp" />
        </GuideStep.Media>
        <GuideStep.Bullets>
          <GuideStep.Bullet color="LIGHT_BLUE">
            Adjust the 3-way Slides so that there is **extra space on one side of the harness**.
          </GuideStep.Bullet>
          <GuideStep.Bullet color="GREEN">
            Attach the Tracker Slide mount onto the side of the harness that you added extra space to.
          </GuideStep.Bullet>
          <GuideStep.Bullet color="YELLOW">
            Attach a normal Slide to both sides of the Chest strap.
          </GuideStep.Bullet>
        </GuideStep.Bullets>
      </GuideStep>
      <GuideStep title="Attach Clasps">
        <GuideStep.Media>
          <MediaFigure src="./images/chest-strap-clasps-img-4879.webp" />
        </GuideStep.Media>
        <GuideStep.Bullets>
          <GuideStep.Bullet color="LIGHT_BLUE">
            Attach the pair of Clasps to the ends of the chest strap, making sure that one side faces up, and the other side faces down.
          </GuideStep.Bullet>
          <GuideStep.Bullet color="YELLOW">
            Double check that the Clasps are able to latch on to each other.
          </GuideStep.Bullet>
        </GuideStep.Bullets>
      </GuideStep>
      <GuideStep title="Start Shoulder Strap">
        <GuideStep.Media>
          <MediaFigure src="./images/shoulder-strap-img-4882.webp" />
          <MediaFigure src="./images/shoulder-strap-threading-pt1-img-4884.webp" />
          <MediaFigure src="./images/shoulder-strap-threading-pt2-img-4886.webp" />
        </GuideStep.Media>
        <GuideStep.Bullets>
          <GuideStep.Bullet color="LIGHT_BLUE">
            Thread normal Slides onto each end of the shoulder straps, again making sure that the silicon part of the strap is touching the paw-print grips.
          </GuideStep.Bullet>
          <GuideStep.Bullet color="GREEN">
            Attach the shoulder straps to the 3-way slides in the same way as you would for a Clasp, threading the strap upwards through the 3-way slide.
          </GuideStep.Bullet>
          <GuideStep.Bullet color="YELLOW">
            Secure the strap end by threading it back through the normal Slides.
          </GuideStep.Bullet>
        </GuideStep.Bullets>
      </GuideStep>
      <GuideStep title="Finish Chest Harness">
        <GuideStep.Media>
          <MediaFigure src="./images/full-shoulder-strap-top-view-img-4890.webp" />
          <MediaFigure src="./images/full-chest-strap-img-4892.webp" />
          <MediaFigure src="./images/full-shoulder-strap-side-img-4889.webp" />
        </GuideStep.Media>
        <GuideStep.Bullets>
          <GuideStep.Bullet color="GREEN">
            Finish attaching each shoulder strap onto the 3-way slides.
          </GuideStep.Bullet>
          <GuideStep.Bullet color="LIGHT_BLUE">
            Put on the chest harness and adjust each of the 3-way slides so that they are well positioned. Tighten down the normal slides so that the harness fits snugly.
          </GuideStep.Bullet>
          <GuideStep.Bullet variant="note">
            If any of the straps are too long, take a moment to trim them down, making sure to leave 1-2in (25-50mm) of strap after each of the normal slides.
          </GuideStep.Bullet>
        </GuideStep.Bullets>
      </GuideStep>
      <GuideStep title="DIY Straps Complete!">
        <GuideStep.Media>
          <MediaFigure src="./images/full-strap-set-img-4894.webp" />
        </GuideStep.Media>
        <GuideStep.Bullets>
          <GuideStep.Bullet color="GREEN">
            You should now have completed a full set of 8 straps! Put them all on, and make sure they fit nicely. Make any final adjustments to the strap lengths.
          </GuideStep.Bullet>
          <GuideStep.Bullet color="LIGHT_BLUE">
            Move on to the next guide and get your software setup! You are so close to being in VR!
          </GuideStep.Bullet>
        </GuideStep.Bullets>
      </GuideStep>
    </GuideStepList>
  </GuideLayout.Content>

</GuideLayout>

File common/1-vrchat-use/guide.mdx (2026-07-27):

import {
  Callout,
  GuideLayout,
  GuideStep,
  GuideStepList,
  LinkButton,
  MediaFigure,
  ToolList,
} from "@openpawlabs/diy-guides-ui";

<GuideLayout>

  <GuideLayout.Header
    title="Daily VR Use!"
    heroImage="./images/vrchat-wave.webp"
    difficulty="easy"
    timeEstimate="5 minutes"
    meta=""
  />

  <GuideLayout.Intro>
    How to use your trackers in VRChat! You will need to do these steps each day you use your trackers in VRChat.
  </GuideLayout.Intro>

  <GuideLayout.Content>
    <GuideStepList>
      <GuideStep title="Launch Apps &amp; Turn on Trackers">
        <GuideStep.Media>
          <MediaFigure
            src="./images/slimevr-calibrate-your-trackers.webp"
            annotations={[
              { type: "rectangle", x1: 70.05, y1: 8.37, x2: 100, y2: 25.4, color: "LIGHT_BLUE" },
            ]}
          />
        </GuideStep.Media>
        <GuideStep.Bullets>
          <GuideStep.Bullet color="MAGENTA">
            Launch SteamVR and SlimeVR.
          </GuideStep.Bullet>
          <GuideStep.Bullet color="GREEN">
            Remove your trackers from the charging dock and turn them all on. SlimeVR will give you a notice that you need to calibrate your trackers.
          </GuideStep.Bullet>
          <GuideStep.Bullet color="LIGHT_BLUE">
            Put the trackers on a stable surface and let them rest for a few seconds to calibrate. You should then see the notice in SlimeVR quickly go away. This will complete the "**Resting Calibration**"
          </GuideStep.Bullet>
        </GuideStep.Bullets>
      </GuideStep>
      <GuideStep title="Put on Trackers &amp; Headset">
        <GuideStep.Media>
          <MediaFigure src="./images/img-4655.webp" />
        </GuideStep.Media>
        <GuideStep.Bullets>
          <GuideStep.Bullet color="LIGHT_BLUE">
            Put on all your straps and attach the trackers to the straps by sliding them down onto the Slide Mounts.
          </GuideStep.Bullet>
          <GuideStep.Bullet color="GREEN">
            Put on your VR headset (HMD).
          </GuideStep.Bullet>
        </GuideStep.Bullets>
      </GuideStep>
      <GuideStep title="Full Reset">
        <GuideStep.Media>
          <MediaFigure
            src="./images/slimevr-full-calibration-1.webp"
            displayRegion={{ x: 0, y: 0.09, width: 100 }}
          />
        </GuideStep.Media>
        <GuideStep.Bullets>
          <GuideStep.Bullet color="GREEN">
            Perform a Full Reset in SlimeVR by letting your arms rest at your sides and standing in a upright with your arms at your sides, making sure your head is facing forward. When ready click the "**Full Reset**" button OR tap on your Left Thigh tracker 3 times.
          </GuideStep.Bullet>
          <GuideStep.Bullet variant="note">
            The "**Full Calibration**" usually only needs to be done once at the start of your session. If you leave your playspace and come back, or remove your headset and put it back on, you will need to redo your "**Full Calibration**".
          </GuideStep.Bullet>
        </GuideStep.Bullets>
      </GuideStep>
      <GuideStep title="Mounting Calibration">
        <GuideStep.Media>
          <MediaFigure src="./images/slimevr-mounting-calibration-2.webp" />
          <MediaFigure src="./images/tracker-orientation.webp" />
        </GuideStep.Media>
        <GuideStep.Bullets>
          <GuideStep.Bullet color="MAGENTA">
            Perform an Automatic Mounting Calibration by getting into the shown "**Ski position**", then press the "**Mounting Calibration**" button OR tap on your Right Thigh tracker 3 times.
          </GuideStep.Bullet>
          <GuideStep.Bullet color="LIGHT_BLUE">
            The mounting calibration will automatically detect the orientation of the trackers on your body part and assign it's location.
          </GuideStep.Bullet>
        </GuideStep.Bullets>
      </GuideStep>
      <GuideStep title="VRChat Calibration">
        <GuideStep.Media>
          <MediaFigure
            src="./images/vrchat-wrist-menu-calibrate-button.webp"
            displayRegion={{ x: 10.58, y: 8.4, width: 89.42 }}
            annotations={[
              { type: "circle", x: 55.07, y: 76.08, radius: 11.41, color: "GREEN" },
            ]}
          />
        </GuideStep.Media>
        <GuideStep.Bullets>
          <GuideStep.Bullet color="GREEN">
            Inside VRChat open up the small menu and click on the "**Calibrate**" button in the small bottom menu.
          </GuideStep.Bullet>
        </GuideStep.Bullets>
      </GuideStep>
      <GuideStep title="Confirm Calibration">
        <GuideStep.Media>
          <MediaFigure
            src="./images/vrchat-calibration-mirror.webp"
            displayRegion={{ x: 29.01, y: 18.78, width: 70.99 }}
          />
        </GuideStep.Media>
        <GuideStep.Bullets>
          <GuideStep.Bullet color="LIGHT_BLUE">
            Stand in a T-Pose to match your avatar, then press the trigger on both controllers at the same time.
          </GuideStep.Bullet>
        </GuideStep.Bullets>
      </GuideStep>
      <GuideStep title="Go Play!">
        <GuideStep.Media>
          <MediaFigure src="./images/vrchat-wave.webp" />
        </GuideStep.Media>
        <GuideStep.Bullets>
          <GuideStep.Bullet color="GREEN">
            That's all you need to do! Go and play in game!
          </GuideStep.Bullet>
        </GuideStep.Bullets>
      </GuideStep>
      <GuideStep title="How to: Quick Reset (Fix Drift)">
        <GuideStep.Media>
          <MediaFigure
            src="./images/yaw-reset-demo.mp4"
            type="video"
          />
        </GuideStep.Media>
        <GuideStep.Bullets>
          <GuideStep.Bullet color="YELLOW">
            While playing if you notice drift you can do a **Quick Reset** by performing a "**Yaw Reset**". Tap twice on your chest tracker to trigger the "**Yaw Reset**".
          </GuideStep.Bullet>
          <GuideStep.Bullet color="LIGHT_BLUE">
            You can do the "**Yaw Reset**" in any position where the trackers are all facing in the same direction as the headset/head tracker.
          </GuideStep.Bullet>
        </GuideStep.Bullets>
      </GuideStep>
      <GuideStep title="How to: Full Reset (Fix Drift)">
        <GuideStep.Media>
          <MediaFigure
            src="./images/full-reset-demo.mp4"
            type="video"
          />
        </GuideStep.Media>
        <GuideStep.Bullets>
          <GuideStep.Bullet color="ORANGE">
            If you are having drift and the Quick Reset did not fix it for you, you can perform a "**Full Reset**" while in game by tapping on your Left Thigh tracker three times.
          </GuideStep.Bullet>
          <GuideStep.Bullet color="LIGHT_BLUE">
            Stand in the same position as the Full Reset when you first put on your trackers, standing with your arms resting at your sides comfortably and headset facing forward.
          </GuideStep.Bullet>
        </GuideStep.Bullets>
      </GuideStep>
      <GuideStep title="How to: Fix Mounting Calibration">
        <GuideStep.Media>
          <MediaFigure
            src="./images/tracker-settings.webp"
            displayRegion={{ x: 0, y: 0, width: 100 }}
            annotations={[
              { type: "circle", x: 84.98, y: 60.95, radius: 14.33, color: "GREEN" },
            ]}
          />
          <MediaFigure src="./images/tracker-orientation-1.webp" />
        </GuideStep.Media>
        <GuideStep.Bullets>
          <GuideStep.Bullet color="YELLOW">
            Noticing that your body parts seem to move in an odd direction when you move them? There is a chance that the automatic mounting calibration did not properly set their orientation.
          </GuideStep.Bullet>
          <GuideStep.Bullet color="GREEN">
            Go to the SlimeVR app and click on the Tracker that is misbehaving. Verify that the "**Mounting orientation**" displays the correct way that your tracker is facing.
          </GuideStep.Bullet>
          <GuideStep.Bullet color="LIGHT_BLUE">
            If the Mounting orientation of the tracker is incorrect select "**Edit Mounting**" then select the correct tracker orientation in the popup window.
          </GuideStep.Bullet>
        </GuideStep.Bullets>
      </GuideStep>
    </GuideStepList>
  </GuideLayout.Content>

</GuideLayout>

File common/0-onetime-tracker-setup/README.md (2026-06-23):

Walks the user through the one-time setup steps for their trackers inside of SlimeVR and VRChat to prepare them to start playing!

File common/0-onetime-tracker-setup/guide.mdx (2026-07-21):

import {
  Callout,
  GuideLayout,
  GuideStep,
  GuideStepList,
  LinkButton,
  MediaFigure,
  ToolList,
} from "@openpawlabs/diy-guides-ui";

<GuideLayout>

  <GuideLayout.Header
    title="One-time Software Setup"
    heroImage="./images/slimevr-window.webp"
    difficulty="moderate"
    timeEstimate="30 minutes"
    meta=""
  />

  <GuideLayout.Intro>
    This guide contains all the steps required to get SlimeVR and VRChat fully setup to use with your trackers. You only need to perform these steps a single time.
  </GuideLayout.Intro>

  <GuideLayout.Content>
    <GuideStepList>
      <GuideStep title="Install SlimeVR on Steam">
        <GuideStep.Media>
          <MediaFigure
            src="./images/slimevr-download.webp"
            annotations={[
              { type: "circle", x: 55.75, y: 94.12, radius: 9.84, color: "LIGHT_BLUE" },
            ]}
          />
          <MediaFigure
            src="./images/slimevr-install-mark-private.webp"
            displayRegion={{ x: 2.63, y: 0, width: 93.27 }}
            annotations={[
              { type: "circle", x: 7.78, y: 52.73, radius: 10.51, color: "GREEN" },
              { type: "circle", x: 79.65, y: 68.59, radius: 24.84, color: "YELLOW" },
            ]}
          />
        </GuideStep.Media>
        <GuideStep.Bullets>
          <GuideStep.Bullet color="LIGHT_BLUE">
            Open the Steam store and add SlimeVR to your library, its completely free!
          </GuideStep.Bullet>
          <GuideStep.Bullet color="GREEN">
            Install SlimeVR on your computer from your Steam Library.
          </GuideStep.Bullet>
          <GuideStep.Bullet variant="button">
            <LinkButton>
              <LinkButton.Item href="steam://advertise/3245490" external>SlimeVR Download (Opens in Steam)</LinkButton.Item>
              <LinkButton.Item href="https://store.steampowered.com/app/3245490/SlimeVR/" external>SlimeVR Download (Steam Store Webpage)</LinkButton.Item>
              <LinkButton.Item href="https://github.com/SlimeVR/SlimeVR-Server" external>SlimeVR Server GitHub</LinkButton.Item>
            </LinkButton>
          </GuideStep.Bullet>
          <GuideStep.Bullet color="YELLOW">
            **Optional Hint:** You can hide this game from your Steam History by marking the game as "Private". This will stop friends being notified each time you launch SlimeVR.
          </GuideStep.Bullet>
        </GuideStep.Bullets>
      </GuideStep>
      <GuideStep title="Open SlimeVR">
        <GuideStep.Media>
          <MediaFigure src="./images/slimevr-lets-get-started-1.webp" />
        </GuideStep.Media>
        <GuideStep.Bullets>
          <GuideStep.Bullet variant="button">
            <LinkButton>
              <LinkButton.Item href="steam://rungameid/3245490" external>Launch SlimeVR (Steam Link)</LinkButton.Item>
            </LinkButton>
          </GuideStep.Bullet>
          <GuideStep.Bullet color="LIGHT_BLUE">
            Open SlimeVR and you should see a Setup screen appear. Click on "**Let's get set up!**" to continue on to the next step.
          </GuideStep.Bullet>
          <GuideStep.Bullet variant="note">
            If you have run SlimeVR before you can get back to this setup screen by going to **Settings > Utilities > Setup Wizard**
          </GuideStep.Bullet>
        </GuideStep.Bullets>
      </GuideStep>
      <GuideStep title="Tracker type &amp; Wi-Fi info">
        <GuideStep.Media>
          <MediaFigure
            src="./images/slimevr-select-tracker-type.webp"
            annotations={[
              { type: "rectangle", x1: 17.5, y1: 69.24, x2: 51.15, y2: 96.14, color: "LIGHT_BLUE" },
            ]}
          />
          <MediaFigure
            src="./images/slimevr-wifi-input-2.webp"
            annotations={[
              { type: "point", x: 21.46, y: 54.61, label: "1", color: "GREEN" },
              { type: "point", x: 21.69, y: 66.12, label: "2", color: "GREEN" },
              { type: "rectangle", x1: 64.54, y1: 69.11, x2: 77.59, y2: 79.19, color: "GREEN" },
              { type: "point", x: 62.02, y: 73.89, label: "3", color: "GREEN" },
            ]}
          />
        </GuideStep.Media>
        <GuideStep.Bullets>
          <GuideStep.Bullet color="LIGHT_BLUE">
            Select "**WiFi-based Slime**" under the "**Third-party or DIY Trackers**" section.
          </GuideStep.Bullet>
          <GuideStep.Bullet color="GREEN">
            Enter your Wi-Fi name and Password into the fields, then click "**Submit!**" to move on to the next step.
          </GuideStep.Bullet>
          <GuideStep.Bullet variant="note">
            If you have have an **advanced/custom Wi-Fi setup** where you have **manually split your Wi-Fi** into separate networks for 2.4Ghz and 5Ghz make sure to input the network name for your 2.4Ghz network.
          </GuideStep.Bullet>
        </GuideStep.Bullets>
      </GuideStep>
      <GuideStep title="Connect Tracker with USB-C">
        <GuideStep.Media>
          <MediaFigure src="./images/slimevr-connect-trackers.webp" />
          <MediaFigure
            src="./images/slimevr-no-trackers-detected.webp"
            annotations={[
              { type: "rectangle", x1: 19.39, y1: 16.44, x2: 80.72, y2: 35.11, color: "RED" },
            ]}
          />
          <MediaFigure src="./images/tracker-plugged-in.webp" />
        </GuideStep.Media>
        <GuideStep.Bullets>
          <GuideStep.Bullet color="GREEN">
            Connect a tracker using a USB-C cable that is connected to your computer, then turn the tracker on using the power switch.
          </GuideStep.Bullet>
          <GuideStep.Bullet color="RED">
            If the tracker does not appear after being plugged in and turned on, try using a different USB-C cable. You need to use a USB-C cable that supports data transfer, some cables may not work if they are **charging-only cables**.
          </GuideStep.Bullet>
        </GuideStep.Bullets>
      </GuideStep>
      <GuideStep title="Wait for Tracker Success">
        <GuideStep.Media>
          <MediaFigure src="./images/slimevr-wifi-connected.webp" />
          <MediaFigure src="./images/slimevr-connecting-to-wifi.webp" />
          <MediaFigure src="./images/slimevr-unable-to-connect-to-wifi.webp" />
        </GuideStep.Media>
        <GuideStep.Bullets>
          <GuideStep.Bullet color="GREEN">
            Wait for the tracker to connect to your Wi-Fi and show up in SlimeVR Server.
          </GuideStep.Bullet>
          <GuideStep.Bullet color="RED">
            If you are getting an error where the tracker is unable to connect to Wi-Fi, click on the "**Previous step**" button and double check your Wi-Fi name and Password are correct.
          </GuideStep.Bullet>
          <GuideStep.Bullet color="ORANGE">
            If you are still having issues, please hop into the Discord server and we will be happy to help you!
          </GuideStep.Bullet>
        </GuideStep.Bullets>
      </GuideStep>
      <GuideStep title="Connect all Trackers">
        <GuideStep.Media>
          <MediaFigure
            src="./images/slimevr-all-trackers-connected.webp"
            annotations={[
              { type: "rectangle", x1: 12.86, y1: 58.44, x2: 35.79, y2: 70.2, color: "GREEN" },
            ]}
          />
          <MediaFigure
            src="./images/slimevr-all-trackers-connected-confirm.webp"
            annotations={[
              { type: "rectangle", x1: 55.64, y1: 51.35, x2: 84.68, y2: 62.57, color: "GREEN" },
            ]}
          />
        </GuideStep.Media>
        <GuideStep.Bullets>
          <GuideStep.Bullet color="LIGHT_BLUE">
            Once the tracker is connected and showing up in SlimeVR unplug it, leaving it turned on. Plug in the next tracker and repeat until all of your trackers are connected.
          </GuideStep.Bullet>
          <GuideStep.Bullet color="GREEN">
            Once they are all connected click on "**I connected all my trackers**" then confirm that you have connected all of your trackers in the popup.
          </GuideStep.Bullet>
        </GuideStep.Bullets>
      </GuideStep>
      <GuideStep title="Assign Trackers to Body Parts">
        <GuideStep.Media>
          <MediaFigure
            src="./images/slimevr-assign-trackers.webp"
            annotations={[
              { type: "rectangle", x1: 0, y1: 56.86, x2: 43.73, y2: 68.93, color: "GREEN" },
              { type: "circle", x: 70.52, y: 31.96, radius: 2.26, color: "YELLOW" },
              { type: "circle", x: 61.45, y: 39.9, radius: 2.21, color: "YELLOW" },
              { type: "circle", x: 79.49, y: 39.9, radius: 2.31, color: "YELLOW" },
              { type: "circle", x: 70.47, y: 49.38, radius: 2.43, color: "YELLOW" },
              { type: "circle", x: 67.17, y: 69.18, radius: 2.47, color: "YELLOW" },
              { type: "circle", x: 73.78, y: 69.33, radius: 2.61, color: "YELLOW" },
              { type: "circle", x: 65.38, y: 89.58, radius: 2.4, color: "YELLOW" },
              { type: "circle", x: 75.74, y: 89.65, radius: 2.39, color: "YELLOW" },
            ]}
          />
          <MediaFigure
            src="./images/slimevr-assign-tracker-body-part.webp"
            annotations={[
              { type: "rectangle", x1: 47.68, y1: 51.48, x2: 85.48, y2: 67.31, color: "LIGHT_BLUE" },
            ]}
          />
          <MediaFigure
            src="./images/slimevr-all-trackers-assigned.webp"
            annotations={[
              { type: "circle", x: 37.48, y: 84.42, radius: 7.24, color: "MAGENTA" },
            ]}
          />
        </GuideStep.Media>
        <GuideStep.Bullets>
          <GuideStep.Bullet color="GREEN">
            Select the option "**x10 Full-Body Set + Elbow tracking**" from the menu on the left
          </GuideStep.Bullet>
          <GuideStep.Bullet color="YELLOW">
            Click on a body part to assign a tracker to it
          </GuideStep.Bullet>
          <GuideStep.Bullet color="LIGHT_BLUE">
            Pickup and move the correct tracker around, this will make it highlight itself in the list. Click on the tracker to assign it to the body part.
          </GuideStep.Bullet>
          <GuideStep.Bullet color="MAGENTA">
            Repeat until all trackers have been assigned to a body part, then click on "**Continue**"
          </GuideStep.Bullet>
        </GuideStep.Bullets>
      </GuideStep>
      <GuideStep title="Automatic Mounting Calibration">
        <GuideStep.Media>
          <MediaFigure src="./images/slimevr-auto-mounting-select.webp" />
          <MediaFigure src="./images/slimevr-mounting-calibration-ski-pose.webp" />
          <MediaFigure src="./images/slimevr-height-setup.webp" />
        </GuideStep.Media>
        <GuideStep.Bullets>
          <GuideStep.Bullet color="MAGENTA">
            Select "**Automatic mounting**" then put on your trackers and follow each of the mounting calibration steps.
          </GuideStep.Bullet>
          <GuideStep.Bullet color="LIGHT_BLUE">
            Once you have completed the automatic mounting calibration guide select "**Next Step**" to continue.
          </GuideStep.Bullet>
          <GuideStep.Bullet color="GREEN">
            On the next step input your height then click "**Continue and save**".
          </GuideStep.Bullet>
        </GuideStep.Bullets>
      </GuideStep>
      <GuideStep title="Select Use Type">
        <GuideStep.Media>
          <MediaFigure
            src="./images/slimevr-use-type-1.webp"
            annotations={[
              { type: "rectangle", x1: 18.55, y1: 45.95, x2: 50.87, y2: 67.24, color: "LIGHT_BLUE" },
            ]}
          />
          <MediaFigure
            src="./images/slimevr-steamvr-standalone.webp"
            annotations={[
              { type: "rectangle", x1: 18.38, y1: 44.01, x2: 50.92, y2: 67.91, color: "LIGHT_BLUE" },
            ]}
          />
          <MediaFigure src="./images/slimevr-launch-steamvr.webp" />
        </GuideStep.Media>
        <GuideStep.Bullets>
          <GuideStep.Bullet color="LIGHT_BLUE">
            Select "**VR Gaming**" on the first screen, and then "**SteamVR**" on the second screen.
          </GuideStep.Bullet>
          <GuideStep.Bullet variant="note">
            If you do not use your PC to run VRChat then you will need to select "**Standalone**" and follow those setup steps.
          </GuideStep.Bullet>
          <GuideStep.Bullet color="GREEN">
            The setup wizard should now be complete!
          </GuideStep.Bullet>
        </GuideStep.Bullets>
      </GuideStep>
      <GuideStep title="Launch SteamVR &amp; Recalibrate">
        <GuideStep.Media>
          <MediaFigure src="./images/slimevr-launch-steamvr-1.webp" />
          <MediaFigure
            src="./images/slimevr-go-to-vrchat-warnings.webp"
            annotations={[
              { type: "rectangle", x1: 74.95, y1: 17.78, x2: 100, y2: 33.02, color: "YELLOW" },
            ]}
          />
        </GuideStep.Media>
        <GuideStep.Bullets>
          <GuideStep.Bullet color="LIGHT_BLUE">
            Launch SteamVR and put on your headset.
          </GuideStep.Bullet>
          <GuideStep.Bullet color="GREEN">
            Perform a full reset and mounting calibration now that your headset is on.
          </GuideStep.Bullet>
          <GuideStep.Bullet color="YELLOW">
            Open up the VRChat Settings wizard by clicking on "**Go to VRChat Warnings**" then go to the next step.
          </GuideStep.Bullet>
        </GuideStep.Bullets>
      </GuideStep>
      <GuideStep title="VRChat Settings (Big Menu)">
        <GuideStep.Media>
          <MediaFigure
            src="./images/slimevr-vrchat-bigmenu-warnings.webp"
            annotations={[
              { type: "rectangle", x1: 10.82, y1: 21.07, x2: 97.58, y2: 96.6, color: "GREEN" },
            ]}
          />
          <MediaFigure
            src="./images/vrchat-bigmenu-1.webp"
            displayRegion={{ x: 15.04, y: 11.16, width: 80.46 }}
            annotations={[
              { type: "rectangle", x1: 25.78, y1: 43.03, x2: 89.74, y2: 52.45, color: "GREEN" },
            ]}
          />
          <MediaFigure
            src="./images/vrchat-bigmenu-2.webp"
            displayRegion={{ x: 4.58, y: 6.8, width: 86.21 }}
            annotations={[
              { type: "rectangle", x1: 27.85, y1: 35.79, x2: 89.29, y2: 45.72, color: "GREEN" },
              { type: "rectangle", x1: 26.45, y1: 63.36, x2: 89.52, y2: 75.16, color: "GREEN" },
              { type: "rectangle", x1: 25.38, y1: 79.12, x2: 90.08, y2: 90.33, color: "GREEN" },
            ]}
          />
        </GuideStep.Media>
        <GuideStep.Bullets>
          <GuideStep.Bullet color="LIGHT_BLUE">
            Open up VRChat, then open up your "**Big Menu**" and go to "**Settings > Tracking & IK**"
          </GuideStep.Bullet>
          <GuideStep.Bullet color="GREEN">
            Adjust the settings to fix the warnings in SlimeVR. Once you complete the "**Big Menu**" section you can move on to the next step.
          </GuideStep.Bullet>
        </GuideStep.Bullets>
      </GuideStep>
      <GuideStep title="VRChat Settings (Wrist &amp; Radial Menu)">
        <GuideStep.Media>
          <MediaFigure
            src="./images/slimevr-vrchat-wrist-menu-warnings.webp"
            annotations={[
              { type: "rectangle", x1: 9.98, y1: 58.13, x2: 98.48, y2: 90.25, color: "GREEN" },
            ]}
          />
          <MediaFigure
            src="./images/vrchat-wrist-menu-1.webp"
            displayRegion={{ x: 20.12, y: 17.79, width: 77.25 }}
            annotations={[
              { type: "rectangle", x1: 21.91, y1: 34.59, x2: 73.95, y2: 43.56, color: "GREEN" },
              { type: "rectangle", x1: 21.07, y1: 60.44, x2: 73.39, y2: 70.6, color: "GREEN" },
            ]}
          />
          <MediaFigure
            src="./images/vrchat-radial-menu-calibration-mirror.webp"
            displayRegion={{ x: 27.28, y: 20.84, width: 68.94 }}
            annotations={[
              { type: "circle", x: 27.57, y: 49.09, radius: 11.99, color: "YELLOW" },
            ]}
          />
        </GuideStep.Media>
        <GuideStep.Bullets>
          <GuideStep.Bullet color="GREEN">
            Open up the small/wrist menu in VRChat, select the Settings cog, then scroll down to "**Tracking & IK**". Adjust the settings to fix the warnings in SlimeVR.
          </GuideStep.Bullet>
          <GuideStep.Bullet color="YELLOW">
            Open up the Radial Menu and turn on your "**Calibration Mirror**" by going to "**Options > Personal Mirror > Settings > Calibration Mirror**".
          </GuideStep.Bullet>
        </GuideStep.Bullets>
      </GuideStep>
      <GuideStep title="SlimeVR &quot;Stay Aligned&quot; Wizard">
        <GuideStep.Media>
          <MediaFigure
            src="./images/slimevr-open-stay-aligned.webp"
            annotations={[
              { type: "rectangle", x1: 72.49, y1: 27.12, x2: 90.92, y2: 35.04, color: "GREEN" },
            ]}
          />
          <MediaFigure
            src="./images/stay-aligned-pose-2.webp"
            annotations={[
              { type: "circle", x: 69.46, y: 76.36, radius: 6.14, color: "LIGHT_BLUE" },
            ]}
          />
          <MediaFigure
            src="./images/stay-aligned-pose-3.webp"
            annotations={[
              { type: "circle", x: 69.8, y: 83.15, radius: 6.5, color: "LIGHT_BLUE" },
            ]}
          />
        </GuideStep.Media>
        <GuideStep.Bullets>
          <GuideStep.Bullet color="GREEN">
            Go back to SlimeVR and you should now see an option to "**Configure Stay Aligned**" in the Checklist on the right side. Click on the "**Open Stay Aligned Wizard**" button.
          </GuideStep.Bullet>
          <GuideStep.Bullet color="LIGHT_BLUE">
            Follow the steps in the **Stay Aligned Wizard** and save each of the poses requested. Stay Aligned helps improve the tracking quality and allows you to go longer before your trackers have any drift.
          </GuideStep.Bullet>
          <GuideStep.Bullet variant="note">
            If you do not see it as an option in the Checklist you can open it up by going to "**Settings > General > Stay Aligned > Setup Stay Aligned**".
          </GuideStep.Bullet>
        </GuideStep.Bullets>
      </GuideStep>
      <GuideStep title="VRChat Quick Calibration">
        <GuideStep.Media>
          <MediaFigure
            src="./images/vrchat-wrist-menu-calibrate-button.webp"
            displayRegion={{ x: 9.36, y: 1.54, width: 90.64 }}
          />
          <MediaFigure
            src="./images/vrchat-calibration-mirror.webp"
            displayRegion={{ x: 23.17, y: 16.62, width: 76.83 }}
          />
        </GuideStep.Media>
        <GuideStep.Bullets>
          <GuideStep.Bullet color="GREEN">
            Back in VRChat open up the small menu and click on the "**Calibrate**" button.
          </GuideStep.Bullet>
          <GuideStep.Bullet color="LIGHT_BLUE">
            Go into a T-Pose to match your avatar in game, then press both triggers on your controllers at the same time to confirm the calibration pose.
          </GuideStep.Bullet>
        </GuideStep.Bullets>
      </GuideStep>
      <GuideStep title="Setup Done!">
        <GuideStep.Media>
          <MediaFigure
            src="./images/vrchat-calibration-complete.webp"
            displayRegion={{ x: 16.23, y: 0, width: 67.61 }}
          />
        </GuideStep.Media>
        <GuideStep.Bullets>
          <GuideStep.Bullet color="GREEN">
            Congratulations! You are now done with all of the one-time setup steps! Your full body tracking should now be working!
          </GuideStep.Bullet>
          <GuideStep.Bullet color="LIGHT_BLUE">
            Read the next guide to see the "Daily" setup steps for your future sessions and tips!
          </GuideStep.Bullet>
        </GuideStep.Bullets>
      </GuideStep>
    </GuideStepList>
  </GuideLayout.Content>

</GuideLayout>

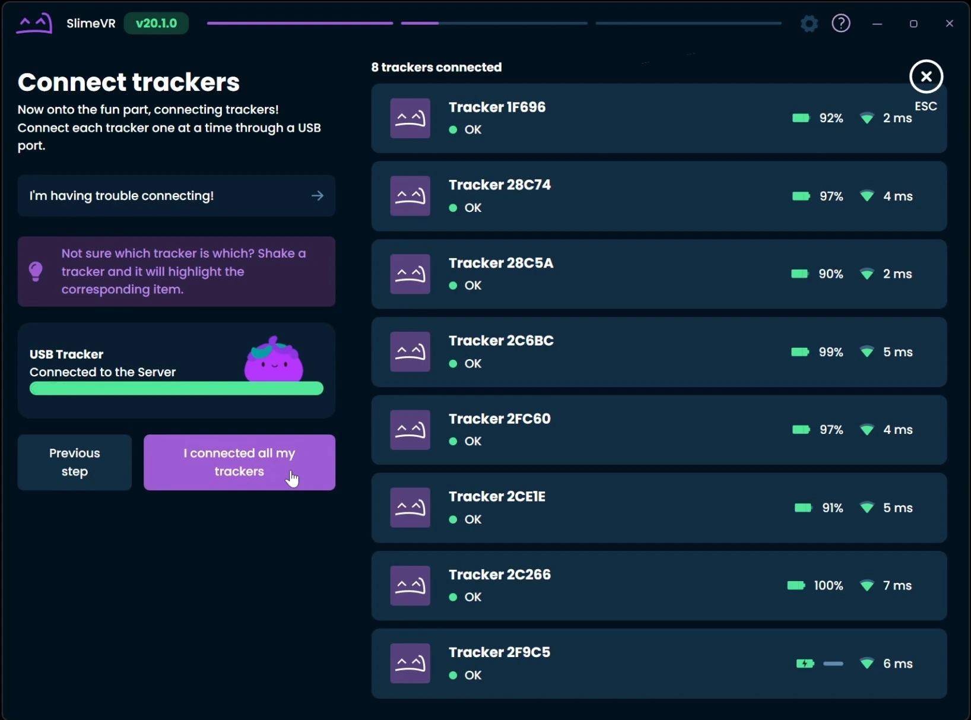
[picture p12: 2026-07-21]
common/0-onetime-tracker-setup/images/slimevr-all-trackers-connected.webp

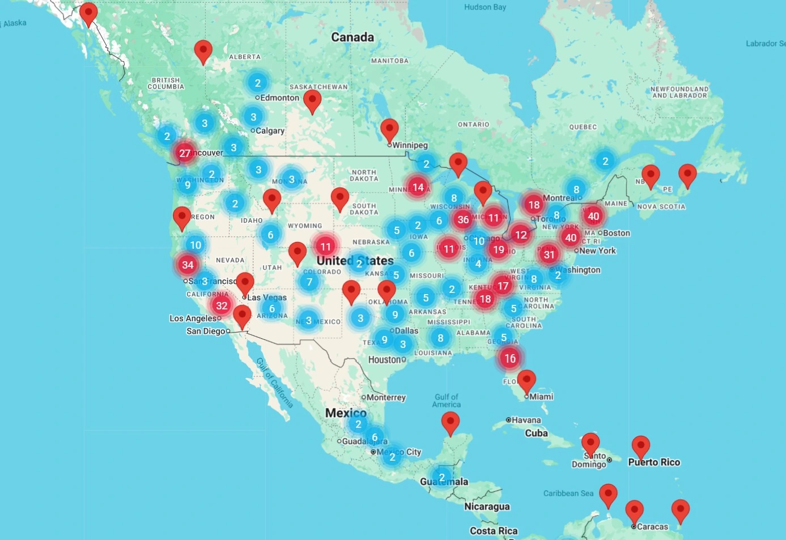
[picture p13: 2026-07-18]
bb-lsm6dsv/0-overview/images/makerspace-map-preview.webp

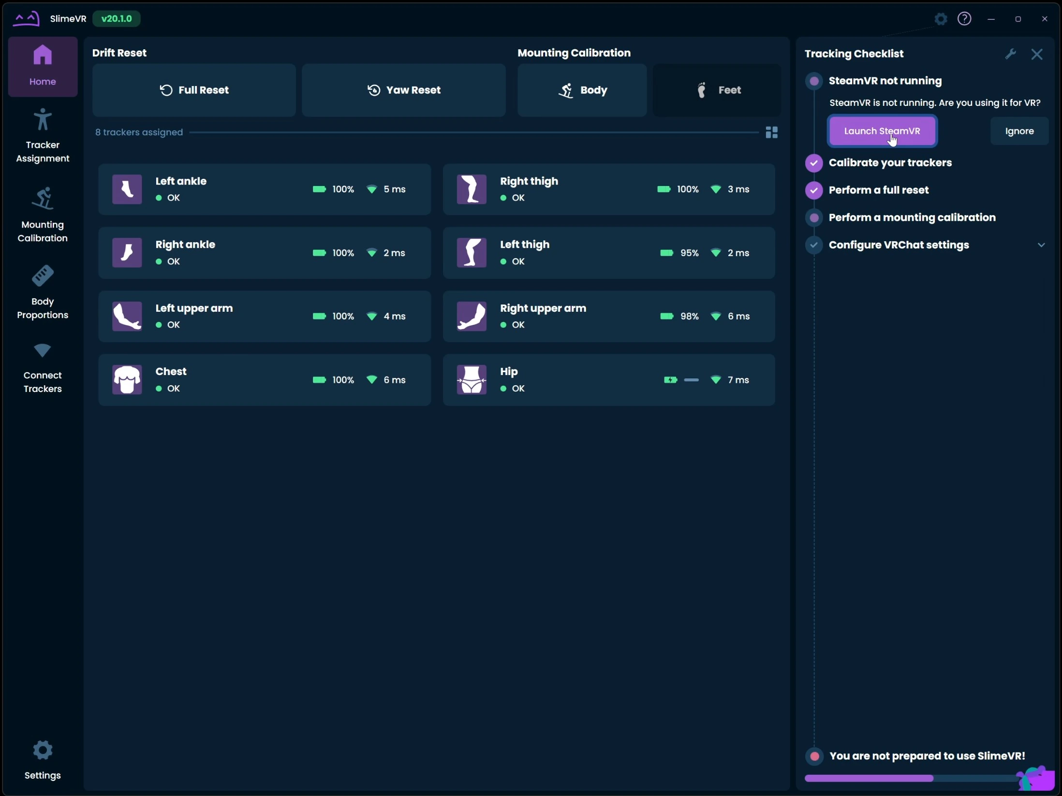
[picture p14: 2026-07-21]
common/0-onetime-tracker-setup/images/slimevr-launch-steamvr-1.webp

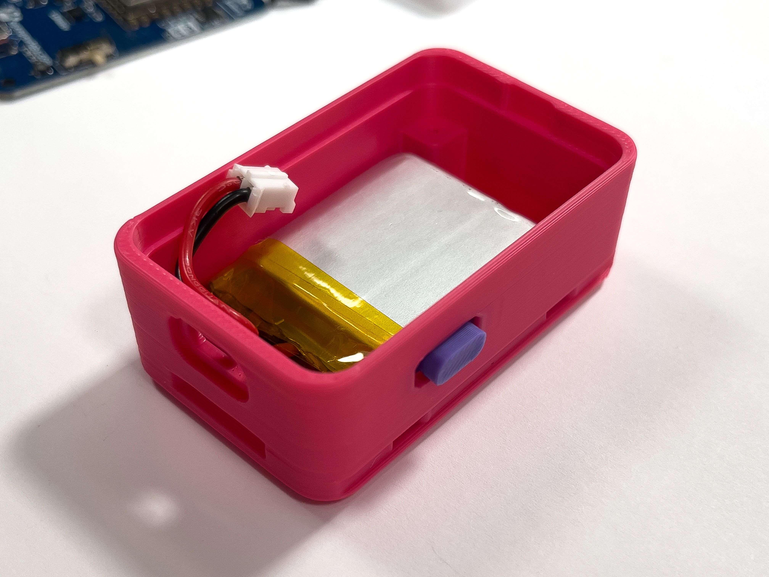
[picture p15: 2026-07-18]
bb-lsm6dsv/2-tracker-assembly/images/img-4607.webp

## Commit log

2026-06-26 wip template base
    [charger-dock-dock-bottom-v3-1.step, openpaw-tracker-case-v7.3mf, openpaw-tracker-case-v7.step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]
2026-07-18 Add images for 3d prints & tracker assembly
2026-07-18 Add basic dock assembly guide images
2026-07-20 Finish writing v1 of 3D Print Guide
    [3-way-glide-slide-v1.step, diy-strap-hardware.3mf, glide-slide-v1.step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]
2026-07-20 Tweak 3d print guide
2026-07-20 Write Tracker Assembly Guide
2026-07-20 Write Charging Dock guide
2026-07-20 Adjust dock assembly crop
2026-07-20 Switch out tracker back image with 4:3 full
2026-07-20 Add Strap Assembly guide (DIY Strap Guide still needed)
2026-07-20 nit update tracker assembly time estimate
2026-07-21 Split battery info to it's own step for hotlinking
2026-07-22 Remove bad link to aliexpress battery
2026-07-27 Add link to more community tracker straps
2026-07-31 Add diy strap guide images
2026-07-31 Write text for DIY Strap Guide
2026-07-31 Update cross-linking text to diy-strap guide
2026-08-01 Add .step source files for 3d prints
    [003-SW.stl, charger-dock-dock-bottom-v3-1.step, charger-dock-dock-top-v3.step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]
2026-08-01 Add real image for DIY Straps
2026-08-03 Minor updates to assembly guide
2026-08-04 Emphasize switch breaking warning
